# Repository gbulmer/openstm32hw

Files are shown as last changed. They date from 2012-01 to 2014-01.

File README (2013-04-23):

openstm32hw README

The aim is to provide Open Source hardware designs for STM32.

This repository grew from a discussion thread on LeafLabs Maple forum:
http://forums.leaflabs.com/topic.php?id=1303

It was initially triggered by ala42 who had released a first cut at libmaple for STM32F4:
http://forums.leaflabs.com/topic.php?id=1268&page=2#post-7828

and siy's hardware design:
http://forums.leaflabs.com/topic.php?id=1303&page=2&replies=46#post-7882

Subdirs:

	MM4 - Leaf Labs Maple Mini clone for 64 pin F1/L1/F4 processors
		in 0.8" width and 2 layers.

	Mini64 - STM32 development board for OpenSTM32
		 Features:
		 - Small (52x38.4mm) breadboard compatible design.
		 - Support for STM32F103/F2xx/F4xx in 64-pin packages.
		 - Uses Eagle 5.1

	Mini48 - Reworked version of Maple Mini suitable for DIY PCB production
		and on-board RTC crystal. Uses Eagle 5.1

	Mini48U - Ultimate version of Mini48. Still suitable for DIY PCB production
		but smaller parts (0402) and optimized layout allowed make it in the
		format of original Maple Mini with 0.6" pin header rows pitch.
		Uses Eagle 5.1

	Mini48SE - This version is very similar to Maple Mini, but it does not 
		preserve its pinout. It also heavily utilizes second side to 
		achieve maximal possible density. As a consequence this version 
		is probably smallest STM32F103Cxx board - it has 0.5" pitch 
		and size is only 50.5x15mm. At the same time board uses no 
		extremely small components - all resistors and capacitors 
		are 0603 (one even 0805), LED - 1206, LDO - 1117.
		Uses Eagle 6.3.0
		The design is tested.

	Mini64SE - Different approach to boards based on MCU in LQFP64 package. 
		It has DIP48 format with 0.8" pitch. The design follows same 
		approach as Mini48SE and utilizes both sides. Separate 
		versions of design for F1 and F2/F4 series are provided. 
		Version for F2/F4 uses different ESD protection and lacks 
		external disconnect cirquitry. These changes are necessary 
		to enable F2/F4 chips work properly in all supported USB modes
		(Device/OTG) and with different powering (self powering and 
		bus powering).
		Uses Eagle 6.3.0 
		Design for F1 is tested, design for F4 still is not yet tested.

	Orone-mini - series of boards intended to be more easily 'DIY-able'
		than LeafLabs Maple-mini, and incorporate several improvements.
		The first boards, Orone-mini-S8x have pins 0.2" wider 
		than Maple-mini. They are otherwise software and pin-compatible 
		with Maple-mini (exception is 'av+' which is intended to 
		improve the power supply capability). 
                Not yet tested.

	PiXe-2: 'Stamp' format, 64pin STM32F103 MCU. Eagle 5.1
                Features: 
		- Dual-in-line 0.1" grid
		- 0805 or larger parts -> easier assembly
		- Internal Maple pins available & re-configurable
		- modest 10mil track/space rules DIY-able

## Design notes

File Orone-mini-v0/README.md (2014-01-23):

Orone-mini designs
==================

Orone-mini's are designed to be software and mostly hardware compatible with LeafLabs Maple-mini. Some improvements have been inspired by Siy's mini48. These boards were also inspired  by the availability of STM32F303 in 48pin LQFP packages. Please note, boards will be tested first using STM32F103 before STM32F303 testing.

Maple-mini improvements
-----------------------
LeafLabs Maple-mini is a very impressive and useful Open Source Hardware development board. It offers approximately 4x more memory and CPU performance than an Arduino UNO, much improved peripherals, and about 50% more I/O pins in a tiny package that fits into a 48pin DIL IC socket. It is supported by an Open Source IDE and library similar to the Arduino UNO. 

However there are areas that are improved by Orone-mini designs:  
1.	Two-layer PCB, and so can be modified using 'free' Eagle CAD (unlike 4-layer which requires a commercial license)  
2.	DIY-assemblable; this is outlined below  
3.	More robust main power supply for operation above 6V; better current supply to e.g. LEDs and external digital electronics  
4.	USB Electro-Static Discharge (ESD) protection for Host PC and Orone-mini  
5.	USB overvoltage protection, protecting Orone-mini's USB power connection  
6.	Extra 2-pin molex socket for easier-to-connect external power  
7.	Power-on indicator  
8.	More robust through-hole mini-USB socket  
9.	Larger silk screen for easier readability  
10.	Silk screen warns of dedicated USB pins, and shows JTAG-SWD pins for extrnal debugger  
11.	Reduced-cost of capacitor C1 by using larger size (2917/7343)  
12.	Access to all STM32F signals; two are not connected to header pins  
13.	Access to the USB input voltage (after polyfuse protection) for 5V power for external electronics  
14.	Access to diode-protected but unregulated input voltage, for external electronics     
15.	Manual control of the USB enumeration mechanism to simplify using STM32F303 manufactured-in USB bootloader. The USB 'DISC' signal, along with ground, can be accessed using a 2 x 0.1" header.  
16.	All parts are straightforward to source, and available from a variety of sources. The Bill of Materials identifies several suppliers
17    Connected USB shield to USB Ground to reduce EM emission, using RC filter to avoid ground loops  

These boards are designed to be DIY-assemblable, but otherwise software and signal compatible with Maple-mini. 

All designs are breadboard-friendly form-factors; all pins are on breadboard 0.1" grid. However, initial designs have header pins spaced 0.8" apart, wider than Maple-mini's 0.6" header pins.

*	**Orone-mini-S8A** - Maple-mini compatible STM32F development board.  
	*Format*: two 20pin headers 0.8" apart. 1206 Components, SOT-223 voltage regulator uses LM2937-style, 'tab-is-ground', footprint  
	Improves on first 5 areas  
	Successfully tested by LeafLabs forum member 'ventosus'.

*	**Orone-mini-S8C** - Superseded by Orone-mini-S8D.    

*	**Orone-mini-S8D** - Superseded by Orone-mini-S8E.    

*	**Orone-mini-S8E** - Maple-mini compatible STM32F development board.    
	*Format*: two 20pin headers 0.8" apart.  
	*Electronics*:1206 Components except NUF2042XV6, C1 is larger 2917/7343, SOT-223 voltage regulator uses LM2937-style, 'tab-is-ground', footprint.  
	PCB requires 6mil track and 6mil space manufacturing capability  
	Similar to Orone-mini-S8A, S8C and S8D, however is physically different from Orone-mini-S8D, and so it's a new part number.  
	Incorporates ten improvements.  
	Not yet tested.

*	**Orone-mini-S8H** - Maple-mini compatible STM32F development board.    
	*Format*: two 20pin headers 0.8" apart.   
	*Electronics*:1206 Components except NUF2042XV6, C1 is larger 2917/7343, SOT-223 voltage regulator uses LM2937-style, 'tab-is-ground', footprint.  
	PCB requires *8mil track and 8mil space* manufacturing capability    
	Similar to Orone-mini-S8A, S8C and S8D, however uses coarser, lower-cost PCB manufacturing rules.  
	Incorporates ten improvements.  
	Successfuly tested by Forum members Crenn and Adam

*	**Orone-mini-S8J** - Maple-mini compatible STM32F development board.    
	*Format*: two 20pin headers 0.8" apart.   
	*Electronics*:1206 Components or larger, except C1 (2917/7343), SOT-223 voltage regulator uses LM2937-style, 'tab-is-ground', footprint.  
	PCB requires *8mil track and 8mil space*, 0.4mm via manufacturing capability    
	Similar to Orone-mini-S8A, S8C and S8D, however uses coarser, lower-cost PCB manufacturing rules.  
	Incorporates sixteen improvements.  
	Not yet tested.

*	**Orone-mini-S8K** - Maple-mini compatible STM32F development board.    
	*Format*: two 20pin headers 0.8" apart.   
	*Electronics*:1206 Components or larger, except C1 (2917/7343), SOT-223 voltage regulator uses LM2937-style, 'tab-is-ground', footprint.  
	PCB requires *8mil track and 8mil space*, 0.4mm via manufacturing capability    
	Similar to Orone-mini-S8A, S8C and S8D, however uses coarser, lower-cost PCB manufacturing rules.  
	Incorporates all improvements.  
	Not yet tested.

*	**CAM/OSHPark-Orone-mini-S8E-v0.cam** - OSHpark.com Eagle CAM file  
	Not yet tested.

Maple-mini Software compatibility
---------------------------------
Orone-mini boards are designed to be completely software and bootloader compatible with Maple-mini. So all existing Maple-mini software should work.

Maple-mini Hardware compatibility
---------------------------------
Orone-mini-S8x boards are not physically compatible with Maple-mini because the pin headers have been moved from 0.6" spacing to 0.8" spacing. This was a result of the increased component size used on Orone-mini. The increased component size is driven by the aim to make Orone-mini DIY-assemblable. 

Orone-mini-S8J pins carry identical signals to Maple-mini. Unlike Orone-mini-S8A-S8H, Orone-mini-S8J 'av+' pin is also identical to Maple-mini. Orone-mini-S8J supplies the 'av+' voltage from the analogue power regulator. The assumption is this will be a lower noise power source than the digital power supply. However this is not yet tested.

Orone-mini version S8A-S8H have one change to the header pins. The Maple-mini's 'av+' power was supplied by a small voltage regulator which might close down, or be damaged when the Maple-mini was used with a power supply voltage much higher than USB's voltage. Orone-mini S8A-S8H supplies power to the 'av+' pin from a slightly larger capacity voltage regulator. The intent is to avoid damage to the small voltage regulator. 

The orone-mini silk screen is larger-size text, and hence contains less information, than Maple-mini. The increase in size is intended to be easier to read, and easier for PCB makers to produce.

DIY-assemblable
---------------
The Maple-mini uses a 4-layer Printed Circuit Board, which can not be modified with the 'free' version of Eagle ECAD. 4-layer boards are also relatively expensive. Hence, this board is a 2-layer board which can be modified using 'free' Eagle ECAD, and the PCB should be much lower cost to manufacture. The board is designed to comply with all Eagle Design Rules from OSHPark.com and Seeedstudio (see Design Rules below)

Many of the Maple-mini parts are very small '0402' size. These have been replaced by 1206 (nine times bigger). This necessitated the increase in board size, which caused the spacing between pin-headers to be increased from 0.6" to 0.8". However 1206 is a component size used in UK schools to introduce 13yo school children to assembling SMD boards. So I hope will be well within the ability of many people. 

Earlier designs used a very small part for Electro-Static Discharge (ESD) protection. This has been replaced by a combination of larger parts, which should be less challenging to assemble. Maple-mini has no ESD protection, so this is additional functionality to Maple-mini.

The Maple-mini has SMD parts on both sides of the board. This is relatively difficult to make using some DIY-friendly SMD techniques. Hence all 'top' SMD components have been changed to 'thru-hole' allowing for a wider range of DIY SMD assembly techniques. The specific components effected are the USB socket, buttons and LEDs. The thru-hole components should also be more robust than the original SMD components.

PCB Design Rules
----------------------
The Printed Circuit Board (PCBs) has been designed using widely available PCB manufacturing tolerances, specifically 8mil track, 8mil space. The smallest drill is 0.5mm (with one 0.4mm exception on S8J/S8K). These manufacturing tolerances are supported by OSHPark.com and Seeedstudio 'Fusion PCB service'. (If you use other PCB manufacturers, would you please feedback your results?)

There are several sets of Design Rule check errors which are flagged by Eagle. None of these prevent the boards being made.

OSHPark Design Rules prevent via 'tenting'; Eagle generated solder mask will not cover *any* vias with solder mask. Hence any text for a silk screen (including tNames and bNames) which print across vias are flagged as "Stop Mask errors".  Small vias should be 'tented'. Set the DRC check->Masks->Limit to 20mil, which will cover vias with a 20mil or smaller (0.5mm) drill with solder mask (tented vias). The Design Rules embedded in this PCB CAD tents vias, so this is only an issue if you load OSHParks DRU file.   

Thanks to
---------
Mark Rafter and Jeff Smith; Tony Wilcox, Chris Evans and David Hannaford of Midlands Micromouse and Robotics Club for advice, encouragement and expertise; Keith, Pete and Bill of Techwizz for discussions and feedback; Siy, feurig, ventosus, ala42, crenn, soycamo and everyone who shared ideas, built boards and contributed at LeafLabs forum; Laen of OSHPark.com for PCB & CAM help and expertise. Special thanks to Pete Harrison for sharing his knowledge, experience and good humour, and to LeafLabs for developing the Maple-IDE and Maple-mini.

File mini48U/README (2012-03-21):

Mini48U is a STM32 development board for OpenSTM32 project (https://github.com/gbulmer/openstm32).
This design is significantly modified Maple Mini R2 and further development of Mini48 
with some changes in schematic (no separate analog ground, added RTC crystal comparing to Maple Mini
and differently connecter RESET pull up resistor) and reworked Mini48 PCB for 0.6" row header spacing.

Copyright (C) LeafLabs (sorry, don't know exact years) 
Changes Copyright (C) 2012 Sergiy Yevtushenko.

Just like original design, modified version is distributed under terms and conditions
of Creative Commons Attribution-ShareAlike license 
(see http://creativecommons.org/licenses/by-sa/3.0/legalcode for details).

Features:
- Small (51.2x18.6mm) breadboard compatible design.
- Compatible with Maple Mini, although ADC noise characteristics might be worse
- RTC crystal on board

Two versions of the board are present. The design of both is very similar, the differences lie in used 
components. Version 0.6.9 uses smaller parts for USB circuit and buttons. Also it attempts to solve 
main problem of original Maple Mini and uses LM1117 for main power LDO in SOT223 package.

The design files were created in Eagle 5.11 (version 6.1) and Eagle 6.1 (version 6.9).

Comments and suggestions are welcome.

Regards,
    Sergiy Yevtushenko <Sergiy.Yevtushenko@gmail.com>

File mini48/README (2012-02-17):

Mini48 is a STM32 development board for OpenSTM32 project (https://github.com/gbulmer/openstm32).
This design is significantly modified Maple Mini R2 with some changes in schematic (no separate
analog ground, added RTC crystal) and completely new PCB (single layer, 0.7" row header spacing).

Copyright (C) LeafLabs (sorry, don't know exact years) 
Changes Copyright (C) 2012 Sergiy Yevtushenko.

Just like original design, modified version is distributed under terms and conditions
of Creative Commons Attribution-ShareAlike license 
(see http://creativecommons.org/licenses/by-sa/3.0/legalcode for details).

Features:
- Small (51.4x21.2mm) breadboard compatible design.
- Compatible with Maple Mini, although ADC noise characteristics might be worse
- RTC crystal on board

The design files were created in Eagle 5.11. Pictures of board can be found at 
https://picasaweb.google.com/101499174242780444159/Mini48.

At present design is single sided and suitable for DIY PCB production, although the requirements
to the production process is quite high - board uses 0.15/0.15mm traces/spaces and designed with
presence of solder mask in mind. The design is optimized for dry film negative photoresist process. 
Design files as-is are ready to use for ordering boards at some PCB production service.
Although they can be used for DIY production too, it might be useful to do following changes 
in the design files before creating photomask:

- Increase width of the dimension rectangle to 0.2mm and include it into top layer and 
  solder mask photomasks.
- Change width of default net class tracks to 0.17mm.
- Change width of vcc net class tracks except GND polygon to 0.32mm. 
- Change width of GND polygon wire to 0.1mm

NOTE: After these changes board will not pass DRC! If you plan make further modifications in the 
PCB changed as described above, change DRC rules accordingly.

Comments and suggestions are welcome.

Regards,
    Sergiy Yevtushenko <Sergiy.Yevtushenko@gmail.com>

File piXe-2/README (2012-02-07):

piXe-2 README

PiXe-2 Is a 'Stamp' format, Microcontroller board using a 64pin (LQFP64) ST Micro STM32F Cortex-M3.

The aim is to develop a board suitable for relatively inexperienced microcontroller users who'd like to progress beyond Arduino ATmega boards.

This design is a 'place-holder' for a new design, see "Work-In-Progress".

Pins are aligned to 0.1" grid, so it can be inserted into breadboard or veroboard.
Pins are on 1.2" pitch, and the board dimensions are 2.9" x 1.4"
It is a double layer board, with all components on one side.

All STM32F pins are brought to header pins except:
- USB - these connect directly to the host PC, 
        so the pins are not available on an pin
- Main Crystal - these have an onboard crystal

The silk screen carries LeafLabs' Maple pin numbers, so existing Maple programs would work unmodified.

All internal connections are Maple compatible, so an unmodified Maple Bootloader would work. 

Internal connections between pins, required for Maple compatibility, use 'solder bridges', and so can be severed. This enables alternative pins to be used for internal connections, though the bootloader will likely need to be modified.

The external power source 'BAT' pin uses a 'solder bridge' to connect to board power, and so can be severed. This would enable the STM32FReal-Time-clock to be powered from an external power source, such as a hearing-aid battery.

The design uses 10mil track 10mil space except for connection to the 0.5mm pitch STM32F. Parts are relatively large 0805, or larger to faciltate hand assembly by less experienced builders. The board has been fabricated using using DIY techniques. 

The Board PDF has had copper pours 'ripped up' to make the tracks easier to see. It has quite intricate ground planes to reduce crosstalk between signals.

Work-In-Progress
----------------
This design is undergoing significant change to redue the board size, accommodate STM32F4, and improve the USB interface electronics. 

WARNING:
This design has not been debugged.

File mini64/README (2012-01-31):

Mini64 is a STM32 development board for OpenSTM32 project (https://github.com/gbulmer/openstm32).

Features:
- Small (52x38.4mm) breadboard compatible design.
- Support for STM32F103/F2xx/F4xx in 64-pin packages.
- 3 separate voltage regulators - two small current LDOs for MCU (separate for analog/digital parts) and one 
  800ma LDO for sourcing external load.
- LiPol battery charger
- RTC crystal on board
- CR2032 battery holder for RTC on board
- Automatic power source selection
- One user button connected as in Maple board
- Two user LEDs, one connected as in Maple board and one connected as in Maple Mini board

The design files were created in Eagle 5.11.

At present design is single sided and suitable for DIY PCB production, although the requirements
to the production process is quite high - board uses 0.15/0.15mm traces/spaces and designed with
presence of solder mask in mind. The design is optimized for dry film negative photoresist process. 
Design files as-is are ready to use for ordering boards at some PCB production service.
Although they can be used For DIY production too, it might be useful to do following changes 
in the design files before creating photomask:

- Increase width of the dimension rectangle to 0.2mm and include it into top layer and 
  solder mask photomasks.
- Change width of default net class tracks to 0.17mm.
- Change width of vcc net class tracks except GND polygon to 0.32mm. 
- Change width of GND polygon wire to 0.1mm

NOTE: After these changes board will not pass DRC! If you plan make further modifications in the 
PCB changed as described above, change DRC rules accordingly.

Comments and suggestions are welcome.

Regards,
    Sergiy Yevtushenko <Sergiy.Yevtushenko@gmail.com>

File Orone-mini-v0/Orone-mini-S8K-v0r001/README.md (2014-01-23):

Orone-mini-S8K-v0r001
=====================

Maple-mini compatible STM32F development board. 

This board is a significant evolution of Orone-mini-S8H. 
Specifically, the NUF2042XV6 USB EMI, termination and ESD device has been replaced. Several makers feedback that it was awkwardly small and fiddly to place.

The replacement part is an STF202-22, which is 4x bigger than the NUF2042XV6.   This STF202-22 is used in such a way that its Vusb ESD and overvoltage protection can't protect the Vusb line. So a separate TVS diode is used to protect the Vusb connection.

All earlier Orone-mini-S8x boards had the AV+ supply voltage header pin connected to the main digital power supply. This was done in order to reduce the problem which had effected Maple-mini boards of too much power being drawn from AV+, and damaging the voltage regulator. 

However, Ventosus made measurements of ADC noise, using circuits powered buy the on-board power supply. These ranked the ADC noise performance as Maple analogue supply best, then Orone-mini-S8H-v0r001's digital supply, then Maple's digital supply. 

Orone-mini-S8K-v0r001's analogue power supply has been connected to av+, to improve Orone-mini's ADC noise. 

PLEASE NOTE the av+ power supply should not be used above an input voltage of approximately 9V and 20mA, as the small voltage regulator may overheat, shutdown or be damaged.

Orone-mini-S8H's power routing and ground plane have been reworked to reduce electrical noise.

This board has not been made and tested yet. It is being released now to gather feedback, and hopefully encourage people to test it. The board has been designed for manufacture using two PCB makers. However, a goal is to ensure it is manufacturable by a wider range of PCB makers, so please feedback.

This is board designed to be DIY-assemblable, but otherwise software and signal compatible with Maple-mini. It has been inspired by some of Siy's mini48 innovations, and also the availability of STM32F303 in 48pin LQFP packages.

It is a breadboard-friendly form-factor; all pins are on breadboard 0.1" grid. Unlike Maple-mini, the two 20pin 0.1" headers are 0.8", and not 0.6" apart. However it is still narrow and short enough to fit into single breadboards.

Maple-mini C1 1206-case-size has been replaced by a 2917 (7343 Metric) case size. 
Orone-mini-S8K brings two extra signals, and two new voltages, to header pads compared to Maple-mini. These additions do not effect any Maple-mini pins. The pads are on the same 0.1" grid as the headers.

Orone-mini improvements over Maple-mini
-----------------------
LeafLabs Maple-mini is a very impressive and useful Open Source Hardware development board. It offers approximately 4x more memory and CPU performance than an Arduino UNO, much improved peripherals, and about 50% more I/O pins in a tiny package that fits into a 40pin DIL IC socket. It is supported by an Open Source IDE and library similar to the Arduino UNO. 

However there are areas that can be improved:  
1.	Two-layer PCB, and so can be modified using 'free' Eagle CAD (unlike 4-layer which requires a commercial license)  
2.	DIY-assemblable; this is outlined elswhere  
3.	More robust main power supply for operation above 6V; better current supply to e.g. LEDs and external digital electronics  
4.	USB Electro-Static Discharge (ESD) protection for Host PC and Orone-mini  
5.	USB overvoltage protection, protecting Orone-mini's USB power connection  
6.	Extra 2-pin molex socket for easier-to-connect external power  
7.	Power-on indicator  
8.	More robust through-hole mini-USB socket  
9.	Larger silk screen for easier readability  
10.	Silk screen warns of dedicated USB pins, and shows JTAG-SWD pins for extrnal debugger  
11.	Reduced-cost of capacitor C1 by using larger size (2917/7343)  
12.	Access to all STM32F signals; two are not connected to header pins  
13.	Access to the USB input voltage (after polyfuse protection) for 5V power for external electronics  
14.	Access to diode-protected but unregulated input voltage, for external electronics     
15.	Manual control of the USB enumeration mechanism to simplify using STM32F303 manufactured-in USB bootloader. The USB 'DISC' signal, along with ground, can be accessed using a 2 x 0.1" header.  
16.	All parts are straightforward to source, and available from a variety of sources. The Bill of Materials identifies several suppliers
17    Connected USB shield to USB Ground to reduce EM emission, using RC filter to avoid ground loops  

All of these improvements are incorporated in the Orone-mini-S8K. The signal driving the User LED is on pin 33, next to pin 31. The DISC signal pad is on the standard 0.1" grid, but is interior to the board. Access to DISC enables the user to easily upload programs into an unprogrammed STM32F303, removing the need for any programming device (e.g. ST-LINK, USB-to-UART, or JTAG).

Vusb and Vx are on the bottom header row, and are not part of the Maple-mini compatible pins. These new voltages should only be used if you understand what you are doing. Vusb in particular is not fully protected, and connects to the host PCs USB socket. The pads are not labelled on top partly due to lack of space, and partly to avoid giving the impression that these are 'easy-to-use' signals.
 
The idea goal is to enable anyone stacking a daughterboard, to use the extra signals and voltages. Putting the pads on a 0.1" grid supports the use of simple daughterboard technology like matrix board, or strip board (e.g. Veroboard).

Maple-mini uses very small components in order to achieve its 0.6" pin-header spacing. They are unsuitable for most makers, and part of the goal of Orone-mini is to be DIY friendly. Also one of those Maple-mini components is expensive and difficult to source, C1, the power supply smoothing capacitor, which is a 1206 case size. Orone-mini replaces C1 with a larger, lower cost, 2917 (7343 Metric) case size. 

PCB Design Rules
----------------------
The Printed Circuit Board (PCBs) has been designed using widely available PCB manufacturing tolerances, specifically 8mil track, 8mil space. The smallest drill is 0.5mm (with one 0.4mm exception).  These manufacturing tolerances are supported by OSHPark.com and Seeedstudio 'Fusion PCB service'. (If you use other PCB manufacturers, would you please feedback your results?)

There are several sets of Design Rule check errors which are flagged by Eagle. None of these prevent the board being made:  

1.	There is a 'bridge' which is flagged as an error, but is manufacturable. The bridge is two touching pieces of copper, and looks like a piece of copper track. It is used to create a separate ground track to the analogue power supply. Eagle treats the bridge as two overlapping tracks, and flags clearance and overlap errors. These is be safe to ignore.  

2.	Several vias are close to SMD component pads. They are the same signal as the pad, and so should not cause electrical issues. However, they do fail default DRC checks. They have no impact on manufacturing the PCB. The errors are 'approved' in the PCB .brd file. C5 has one Clearance DRC error with a ground via. FUSE1 has 1 Overlap DRC error with a power via. D1 has 1 Overlap DRC error with a via.

3.    Two vias are near the 'tab' pin of the REG1 regulator cause DRC errors. The vias should conduct heat through to the larger area of copper on the reverse side of the board. There are several other 'heat-path vias' in the component side copper pour, but vias in REG1 tab-pin should be more effective. Note the vias are placed just beyond the edge of the tab-pin silk screen to reduce the likelihood of solder 'voids' under the pin.  

4.	The crystal routing is quite intricate. It contains Clearance (1), Keepout (3), Restrict (6) DRC Errors.

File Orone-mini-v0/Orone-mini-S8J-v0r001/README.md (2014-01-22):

Orone-mini-S8J-v0r001
=====================

Maple-mini compatible STM32F development board. 

This board is a significant evolution of Orone-mini-S8H. 
Specifically, the NUF2042XV6 USB EMI, termination and ESD device has been replaced. Several makers feedback that it was awkwardly small and fiddly to place.

The replacement part is an STF202-22, which is 4x bigger than the NUF2042XV6.   This STF202-22 is used in such a way that its Vusb ESD and overvoltage protection can't protect the Vusb line. So a separate TVS diode is used to protect the Vusb connection.

All earlier Orone-mini-S8x boards had the AV+ supply voltage header pin connected to the main digital power supply. This was done in order to reduce the problem which had effected Maple-mini boards of too much power being drawn from AV+, and damaging the voltage regulator. 

However, Ventosus made measurements of ADC noise, using circuits powered buy the on-board power supply. These ranked the ADC noise performance as Maple analogie supply best, then Orone-mini-S8H-v0r001's digital supply, then Maple's digital supply. 

Orone-mini-S8J-v0r001's analogue power supply has been connected to av+, to improve Orone-mini's ADC noise. 

PLEASE NOTE the av+ power supply should not be used above an input voltage of approximately 9V and 20mA, as the small voltage regulator may overheat, shutdown or be damaged.

Orone-mini-S8H's power routing and ground plane have been reworked to reduce electrical noise.

This board has not been made and tested yet. It is being released now to gather feedback, and hopefully encourage people to test it. The board has been designed for manufacture using two PCB makers. However, a goal is to ensure it is manufacturable by a wider range of PCB makers, so please feedback.

This is board designed to be DIY-assemblable, but otherwise software and signal compatible with Maple-mini. It has been inspired by some of Siy's mini48 innovations, and also the availability of STM32F303 in 48pin LQFP packages.

It is a breadboard-friendly form-factor; all pins are on breadboard 0.1" grid. Unlike Maple-mini, the two 20pin 0.1" headers are 0.8", and not 0.6" apart. However it is still narrow and short enough to fit into single breadboards.

Maple-mini C1 1206-case-size has been replaced by a 2917 (7343 Metric) case size. 
Orone-mini-S8J brings tw extra signals, and two new voltages, to header pads compared to Maple-mini. These additions do not effect any Maple-mini pins. The pads are on the same 0.1" grid as the headers.

Orone-mini improvements over Maple-mini
-----------------------
LeafLabs Maple-mini is a very impressive and useful Open Source Hardware development board. It offers approximately 4x more memory and CPU performance than an Arduino UNO, much improved peripherals, and about 50% more I/O pins in a tiny package that fits into a 40pin DIL IC socket. It is supported by an Open Source IDE and library similar to the Arduino UNO. 

However there are areas that can be improved:  
1.	DIY-assemblable - all parts are approaximately 1206 size or larger 
2.	Robust operation above 6V while providing current to e.g. LEDs and electronics  
3.	USB Electrostatic Discharge (ESD) protecting the Host PC and Orone-mini  
4.	Two-pin Molex kk Socket for easier-to-connect external power source
5.	Power-on indicator  
6.	Access to all STM32F signals; two signals are not connected to Maple-mini header pins    
7.	Access to Vusb, the 'raw' USB voltage source, and the 'pre-regulator' voltage Vx

All of these improvements are incorporated in the Orone-mini-S8J. The signal driving the User LED is on pin 33, next to pin 31. The DISC signal pad is on the standard 0.1" grid, but is interior to the board. Access to DISC enables the user to easily upload programs into an unprogrammed STM32F303, removing the need for any programming device (e.g. ST-LINK, USB-to-UART, or JTAG).

Vusb and Vx are on the bottom header row, and are not part of the Maple-mini compatible pins. These new voltages should only be used if you understand what you are doing. Vusb in particular is not fully protected, and connects to the host PCs USB socket. The pads are not labelled on top partly due to lack of space, and partly to avoid giving the impression that these are 'easy-to-use' signals.
 
The idea goal is to enable anyone stacking a daughterboard, to use the extra signals and voltages. Putting the pads on a 0.1" grid supports the use of simple daughterboard technology like matrix board, or strip board (e.g. Veroboard).

Maple-mini uses very small components in order to achieve its 0.6" pin-header spacing. They are unsuitable for most makers, and part of the goal of Orone-mini is to be DIY freiendly. Also one of those Maple-mini components is expensive and difficult to source, C1, the power supply smoothing capacitor, which is a 1206 case size. Orone-mini replaces C1 with a larger, lower cost, 2917 (7343 Metric) case size.

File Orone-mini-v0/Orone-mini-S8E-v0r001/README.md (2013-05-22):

Orone-mini-S8E-v0r001
=====================

Maple-mini compatible STM32F development board. 

This board has not been made and tested yet. It is being released now to gather feedback, and hopefully encourage people to test it. The board has been designed for manufacture using two PCB makers. However, a goal is to ensure it is manufacturable by a wider range of PCB makers, so please feedback.

This is board designed to be DIY-assemblable, but otherwise software and signal compatible with Maple-mini. It has been inspired by some of Siy's mini48 innovations, and also the availability of STM32F303 in 48pin LQFP packages.

It is a breadboard-friendly form-factor; all pins are on breadboard 0.1" grid. Unlike Maple-mini, the two 20pin 0.1" headers are 0.8", and not 0.6" apart. However it is still narrow and short enough to fit into single breadboards.

Maple-mini C1 1206-case-size has been replaced by a 2917 (7343 Metric) case size. 
Orone-mini-S8E brings two extra signals, and two extra voltages to pads compared to Maple-mini. One signal (for the LED) and the two voltages are on the headers 0.1" grid. The USB 'DISC' signal is paired with a Ground pad, 0.1" away, enabling DISC to be shorted to ground with a jumper using a 2x0.1" header.

Maple-mini improvements
-----------------------
LeafLabs Maple-mini is a very impressive and useful Open Source Hardware development board. It offers approximately 4x more memory and CPU performance than an Arduino UNO, much improved peripherals, and about 50% more I/O pins in a tiny package that fits into a 40pin DIL IC socket. It is supported by an Open Source IDE and library similar to the Arduino UNO. 

However there are areas that can be improved:  
1.	DIY-assemblable; this is outlined below  
2.	Robust operation above 6V while providing current to e.g. LEDs and electronics  
3.	USB Electro-static Discharge (ESD) protecting the Host PC and Orone-mini  
4.	Socket for easier-to-connect external power  
5.	Power-on indicator  
6.	Reduced-cost of capacitor C1 by using larger size (2917/7343)  
7.	Access to all STM32F signals; two are not connected to header pins  
8.	Access to the USB input voltage (after polyfuse protection)  
9.	Access to diode-protected but unregulated input voltage  
10.	USB 'DISC' signal on 2 x 0.1" header to simplify STM32F303 USB boot

All of these improvements are incorporated in the Orone-mini-S8E. The signal driving the User LED (pin 33) is on a pad next to 31. The DISC signal pad is harder to access. It is not on the standard 0.1" grid, and is interior to the board. 

Vusb and Vx are in line with the bottom header row. These voltages should only be used if you understand what you are doing. Vusb is protected by the polyfuse (FUSE1), and is otherwise connected to the host PCs USB socket. The pads are not labelled on top partly due to lack of space, and partly to avoid giving the impression that these are 'safe' signals.

The aim of putting the extra signals on pads is to enable anyone making a daughterboard to easily access the extra signals and voltages. Putting signal the pads on a 0.1" grid supports the use of simple daughterboard technology like matrix board, or strip board (e.g. Veroboard).

Maple-mini uses very small components in order to achieve its 0.6" pin-header spacing. Maple-mini uses a 1206 case size for C1, the power supply smoothing capacitor. This size is expensive and difficult to source. On this Orone-mini, C1 has been replaced by a 2917 (7343 Metric) case size which is much lower cost.

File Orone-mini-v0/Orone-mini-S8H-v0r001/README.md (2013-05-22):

Orone-mini-S8H-v0r001
=====================

Maple-mini compatible STM32F development board. 

This board has not been made and tested yet. It is being released now to gather feedback, and hopefully encourage people to test it. The board has been designed for manufacture using two PCB makers. However, a goal is to ensure it is manufacturable by a wider range of PCB makers, so please feedback.

This is board designed to be DIY-assemblable, but otherwise software and signal compatible with Maple-mini. It has been inspired by some of Siy's mini48 innovations, and also the availability of STM32F303 in 48pin LQFP packages.

It is a breadboard-friendly form-factor; all pins are on breadboard 0.1" grid. Unlike Maple-mini, the two 20pin 0.1" headers are 0.8", and not 0.6" apart. However it is still narrow and short enough to fit into single breadboards.

Maple-mini C1 1206-case-size has been replaced by a 2917 (7343 Metric) case size. 
Orone-mini-S8H brings two extra signals, and two more voltages, to header pads compared to Maple-mini. The pads are on the same 0.1" grid as the headers.

Maple-mini improvements
-----------------------
LeafLabs Maple-mini is a very impressive and useful Open Source Hardware development board. It offers approximately 4x more memory and CPU performance than an Arduino UNO, much improved peripherals, and about 50% more I/O pins in a tiny package that fits into a 40pin DIL IC socket. It is supported by an Open Source IDE and library similar to the Arduino UNO. 

However there are areas that can be improved:  
1.	DIY-assemblable; this is outlined below  
2.	Robust operation above 6V while providing current to e.g. LEDs and electronics  
3.	USB Electro-static Discharge (ESD) protecting the Host PC and Orone-mini  
4.	Socket for easier-to-connect external power  
5.	Power-on indicator  
6.	Reduced-cost of capacitor C1 by using larger size (2917/7343)  
7.	Access to all STM32F signals; two are not connected to header pins  
8.	Access to the USB input voltage (after polyfuse protection)  
9.	Access to diode-protected but unregulated input voltage  
10.	USB 'DISC' signal on 2 x 0.1" header to simplify STM32F303 USB boot

All of these improvements are incorporated in the Orone-mini-S8H. The signal driving the User LED (pin 33) is on a pad aligned with the top header pins, next to 31. The DISC signal pad is harder to access. It is on the standard 0.1" grid, but is interior to the board.

Vusb and Vx are in line with the bottom header row. These voltages should only be used if you understand what you are doing. Vusb is protected by the polyfuse (FUSE1), and is otherwise connected to the host PCs USB socket. The pads are not labelled on top partly due to lack of space, and partly to avoid giving the impression that these are 'safe' signals.
 
The aim of putting the extra signals on pads is to enable anyone making a daughterboard to easily access the extra signals and voltages. Putting the pads on a 0.1" grid supports the use of simple daughterboard technology like matrix board, or strip board (e.g. Veroboard).

Maple-mini uses very small components in order to achieve its 0.6" pin-header spacing. Maple-mini uses a 1206 case size for C1, the power supply smoothing capacitor. This size is expensive and difficult to source. On this Orone-mini, C1 has been replaced by a 2917 (7343 Metric) case size which is much lower cost.

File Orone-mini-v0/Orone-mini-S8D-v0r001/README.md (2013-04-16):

Orone-mini-S8D-v0r001
=====================

Maple-mini compatible STM32F development board. 

This board has not been made and tested yet. It is being released now to gather feedback, and hopefully encourage people to test it. The board has been designed for manufacture using two PCB makers. However, a goal is to ensure it is manufacturable by a wider range of PCB makers, so please feedback.

This is board designed to be DIY-assemblable, but otherwise software and signal compatible with Maple-mini. It has been inspired by some of Siy's mini48 innovations, and also the availability of STM32F303 in 48pin LQFP packages.

It is a breadboard-friendly form-factor; all pins are on breadboard 0.1" grid. Unlike Maple-mini, the two 20pin 0.1" headers are 0.8", and not 0.6" apart. However it is still narrow and short enough to fit into single breadboards.

Maple-mini C1 1206-case-size has been replaced by a 2917 (7343 Metric) case size. 
Orone-mini-S8D brings two extra signals compared to Maple-mini to pads on the same 0.1" grid as the headers.

Maple-mini improvements
-----------------------
LeafLabs Maple-mini is a very impressive and useful Open Source Hardware development board. It offers approximately 4x more memory and CPU performance than an Arduino UNO, much improved peripherals, and about 50% more I/O pins in a tiny package that fits into a 40pin DIL IC socket. It is supported by an Open Source IDE and library similar to the Arduino UNO. 

However there are areas that can be improved:  
1.	DIY-assemblable  
2.	Robust operation above 6V while providing current to e.g. LEDs and electronics  
3.	USB Electro-static Discharge (ESD) protecting the Host PC and Orone-mini  
4.	Socket for easier-to-connect external power  
5.	Power-on indicator  
6.	Access to all STM32F signals; two signals are not connected to header pins    

All of these improvements are incorporated in the Orone-mini-S8D. The signal driving the User LED (pin 33) is on a pad next to 31. The DISC signal pad is harder to access. It is on the standard 0.1" grid, but is interior to the board. The idea is to enable anyone stacking a daughterboard, to use the extra two signals. Putting the signal pads on a 0.1" grid supports the use of simple daughterboard technology like matrix board, or strip board (e.g. Veroboard).

Maple-mini uses very small components in order to achieve its 0.6" pin-header spacing. One of those components is expensive and difficult to source, C1, the power supply smoothing capacitor. Maple-mini uses a 1206 case size for C1. This has been replaced by a 2917 (7343 Metric) case size.

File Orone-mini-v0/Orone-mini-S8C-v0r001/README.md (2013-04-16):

Orone-mini-S8C-v0r001
=====================

Maple-mini compatible STM32F development board. 

This board has not been made and tested yet. It is being released now to gather feedback, and hopefully encourage people to test it. The board has been designed for manufacture using two PCB makers. However, a goal is to ensure it is manufacturable by a wider range of PCB makers, so please feedback.

This is board designed to be DIY-assemblable, but otherwise software and signal compatible with Maple-mini. It has been inspired by some of Siy's mini48 innovations, and also the availability of STM32F303 in 48pin LQFP packages.

It is a breadboard-friendly form-factor; all pins are on breadboard 0.1" grid. Unlike Maple-mini, the two 20pin 0.1" headers are 0.8", and not 0.6" apart. However it is still narrow and short enough to fit into single breadboards.

Maple-mini C1 1206-case-size has been replaced by a 2917 (7343 Metric) case size. 

Maple-mini improvements
-----------------------
LeafLabs Maple-mini is a very impressive and useful Open Source Hardware development board. It offers approximately 4x more memory and CPU performance than an Arduino UNO, much improved peripherals, and about 50% more I/O pins in a tiny package that fits into a 40pin DIL IC socket. It is supported by an Open Source IDE and library similar to the Arduino UNO. 

However there are areas that can be improved:  
1.	DIY-assemblable  
2.	Robust operation above 6V while providing current to e.g. LEDs and electronics  
3.	USB Electro-static Discharge (ESD) protecting the Host PC and Orone-mini  
4.	Socket for easier-to-connect external power  
5.	Power-on indicator  
6.	Access to all STM32F signals; two are not connected to header pins  

All of these improvements are incorporated in the Orone-mini-S8C. The two signals of item 6, are not easy to access. Though both signals are on the standard 0.1" grid, they are on the interior of the board, and one signal is only available from the User LED pads. The idea is to enable anyone stacking a daughterboard, to use the extra two signals. Putting the signal pads on a 0.1" grid supports the use of simple daughterboard technology like matrix board, or strip board (e.g. Veroboard).

Maple-mini uses very small components in order to achieve its 0.6" pin-header spacing. One of those components is expensive and difficult to source, C1, the power supply smoothing capacitor. Maple-mini uses a 1206 case size for C1. This has been replaced by a 2917 (7343 Metric) case size.

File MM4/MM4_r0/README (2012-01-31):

This design is a clone of Leaf Labs Maple Mini board (called MM4) with the following variations
	from the original:

	- 0.8 inch pitch between connectors rather than 0.6". This means dual rows of 
		sip connectors are required rather than a 40 pin dip (a socket layout can 
		easily be defined for either LeafLabs or MM4 using 3 sip connectors.)

	- identical pin functions except for the above mentioned pitch change.

	- two layer layout in Eagle which can be modified with the free version of 
		Eagle (original was done with Eagle v6.1). Ground planes that are 
		as large as practical are used given the two layer constraint (modification 
		to internal power/ground planes is, of course, fairly straightforward, 
		but requires the much more expensive Eagle license).

	- 64 pin processor that can be STM32F10xC/D/E orSTM32F4 or STM32L1 series. This means 
		the F1 chip variants with larger memories can be used or the L1 low power series 
		(F1 and L1 require two solder bridge jumpers to be installed), or the faster Cortex-M4 F4 series.

	- considerably less detailed top silkscreen layer in this version of MM4.

	- The USB termination function has been re-implemented with a dedicated USB terminator
		chip that contains the termination resistors and the signalling resistor to
		describe the board to an up-stream host as a full speed USB peripheral.
		The disconnect function is then separately implemented with an open collector 
		inverter. The original implemented the signalling and disconnect via a 
		transistor/resistor network.

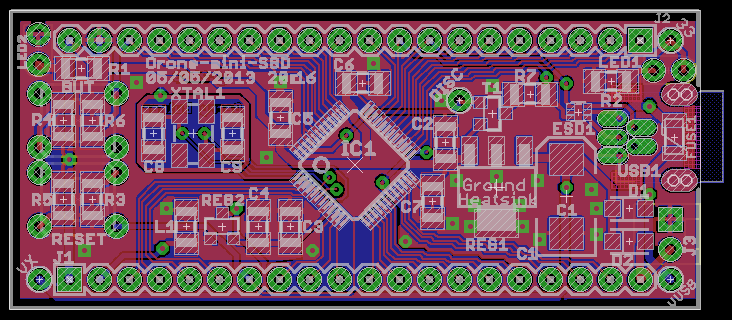
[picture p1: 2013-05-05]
Orone-mini-v0/Orone-mini-S8D-v0r001/Orone-mini-S8D-v0r001.png

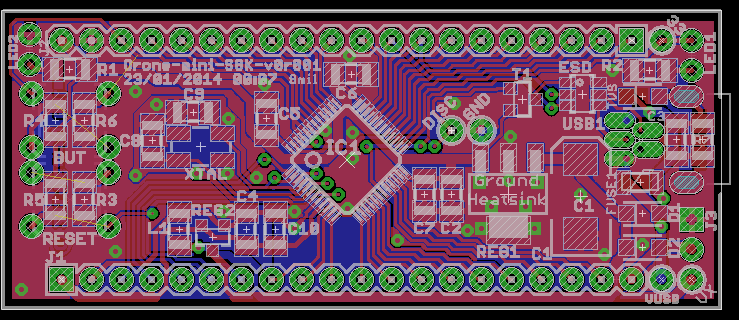
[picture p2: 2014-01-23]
Orone-mini-v0/Orone-mini-S8K-v0r001/Orone-mini-S8K-v0r001.brd.png

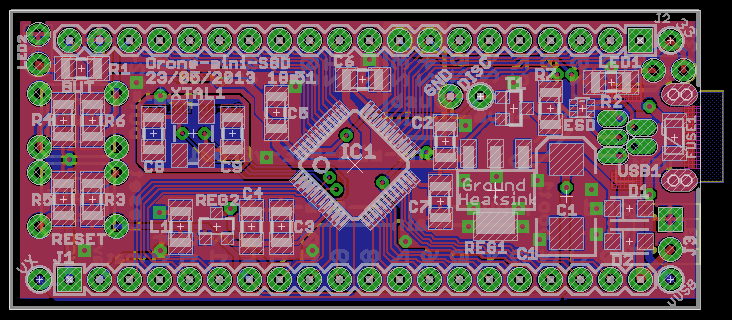
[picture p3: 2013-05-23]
Orone-mini-v0/Orone-mini-S8E-v0r001/Orone-mini-S8E-v0r001.png

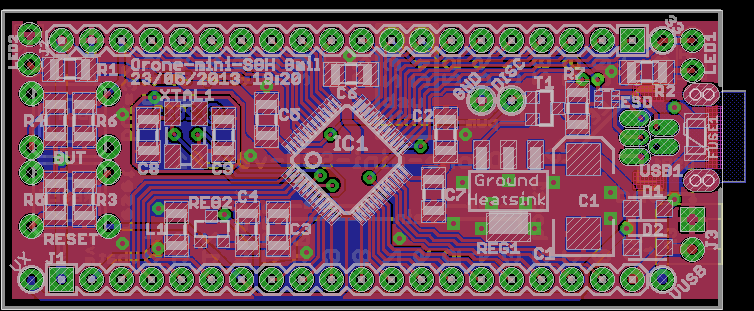
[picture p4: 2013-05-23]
Orone-mini-v0/Orone-mini-S8H-v0r001/Orone-mini-S8H-v0r001.png

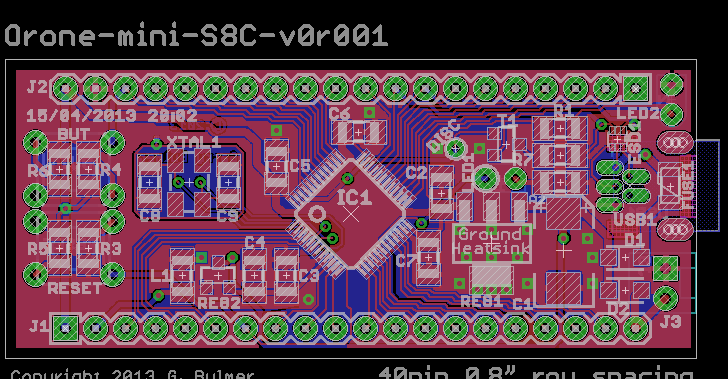
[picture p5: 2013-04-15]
Orone-mini-v0/Orone-mini-S8C-v0r001/Orone-mini-S8C-v0r001.png

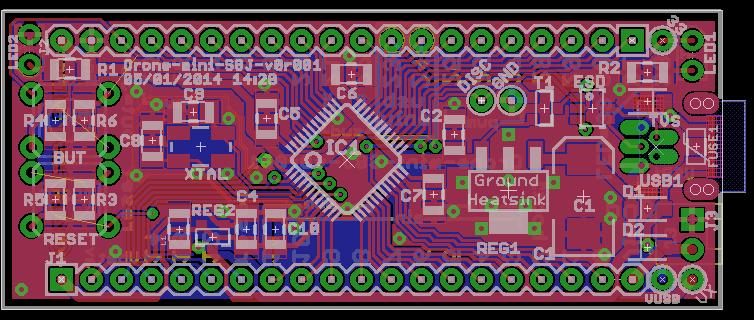
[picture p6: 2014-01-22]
Orone-mini-v0/Orone-mini-S8J-v0r001/Orone-mini-S8J-v0r001.png

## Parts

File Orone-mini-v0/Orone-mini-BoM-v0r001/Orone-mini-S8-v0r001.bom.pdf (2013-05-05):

Orone-mini-S8 Parts | Partlist exported at 14/04/2013 09:03
Qty | Parts | Value/Part # | Device | RS | Farnell | Future | Comment
0 | IC1 | STM32F103CB | STM32F103CB | 402-273 | 2215215 | STM32F103 CB | LQFP48 STM32F103
1 | | STM32F303CC | | 772-4857 | | | LQFP48 STM32F303
1 | L1 | 2512066017Y1 FAIR-RITE | INDUCTOR 1206 | 466-9603 | 1612060 | | Reduce electrical noise into analogue ground, av-0.08R 1A, 600R@100MHz
4 | R1, R2, R3, R4 | 1k | RESISTOR 1206 | 740-9117 (5%) | 2073877 | | LED current limit & switch pull-up/down, 10% okay
2 | R5, R6 | 10k | RESISTOR 1206 | 740-9081 (1%) | 2073878 | | switch pull-up/down, 10% tolerance is okay
1 | R7 | 1.5k | RESISTOR 1206 | 223-2287 (1%) or 740-9123 (5%) | 2073891 | | USB pull-up resistor
1 | C1 | 100uF/16V | CAP_POL7343 | 496-3646 or 684-3926 | 1754094 or 1658709 | | Main power smoothing capacitor must be able to withstand the external power Vin voltage
1 | C2 | 10uF | CAP 1206 | 723-6565 or 758-8093 etc. | 2113071 or 1828831 | | Multi-layer Ceramic X7R, 6.3V or higher
1 | C3 | 10nF | CAP 1206 | 669-8410 or 264-4141 etc | 1759350 or 1414713 | | Multi-layer Ceramic X7R, 6.3V or higher
4 | C4, C5, C6, C7 | 1uF | CAP 1206 | 648-0733 or 669-8448 etc. | 1759436 or 9227865 | | Multi-layer Ceramic X7R, 6.3V or higher
2 | C8, C9 | 18pF | CAP 1206 | 698-2841 or 648-0935 (0805) | 1650895 or 2218878 | | Hard to get in 1206, RS 698-2841 is 15pF, or RS 648-0935 (0805 case)
1 | XTAL1 | 5RCA08000123TF80Q3 | CRYSTAL 5X3.2 | 728-8272 | | | 8MHz 5x3.2mm 4-pad SMD Crystal
2 | BUT, RESET | FSM6JH | TAC_SWITCH PTH 6mm | 758-1953 or 758-1957 or 756-1543
1 | LED1 | L-2060GD | LED1.8MM-W | 228-5427 | 1142454 or 1045497 | | 1.8MM (T-3/4) Green User LED - e.g. Kingbright, Vishay or generic
1 | LED2 | L-2060ID or MCL914SRD | LED1.8MM-W | 228-5411 | 1142456 or 1045495 | | LED 1.8MM (T-3/4) Red Power-On LED - e.g. Kingbright, Vishay or generic
2 | D1, D2 | PMEG3010ER or PMEG3010EH | DIODE-SCHOTTKY SOD-123W | 485-606 | 1907686 | | 1A 30V or higher Schottky Diode
1 | T1 | PDTA114ET or MMUN2111LT1G | ES_PNP-DRIVER SOT23-3 | 484-3441 | 1907673 or 9556702 | | PNP ‘Digital Transistor’ includes
1 | REG1 | MIC5209-3.3YS | V_REG_LM293 7 SOT223 | 727-2586 | 2100322 or 1556725
1 | REG2 | MCP1703T-3302E/CB | MCP170X SOT23 | 669-4907 | 1439518
1 | ESD1 | NUF2042XV6 | NUF2042XV6 SOT563 | | | NUF2042XV 6T1G | NUF2042XV6T ESD protection and USB filter
1 | FUSE1 | 1206L050 (Littelfuse) or nanoSMDC050F/13.2 (TE) | PTCSMD | 138-679 | 1596993 or 1345942 | | 6V, 500mA Polyfuse 0.7R Max, 0.4R Typical. Littelfuse part numbers may be 1206L050YR or 1206L050-C
2 | J1, J2 | e.g. AW 110/20-T (Assman) | M20 | 674-2343 | | | 2 x 20pin 0.1” Headers. Almost any 0.1" pitch header pins could be used, could also use 0.1" pitch sockets.
1 | USB1 | USB-Mini-B/AB thru-hole. 56579-0519 or 54819-0519 Molex | USB-MINIB TH-ODRILL | 515-2011 or 515-2005 | 1125347 or 2133828 or 9786465 | | Thru-hole USB Mini B & AB same footprint
1 | J3 | Molex KK 22-23-2021 or 22-11-2022 or 22-27-2021 | M02POLAR | 679-5583 or 679-5515 or 483-8461 | 1462926 or 1865212 or 9731148 | | 2-pin, polarised, "External power" socket

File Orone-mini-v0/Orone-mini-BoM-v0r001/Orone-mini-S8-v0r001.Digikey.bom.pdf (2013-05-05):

Digi-Key Part # | Manufacturer | Manufacturers Part # Reference | Quantity 1 | Quantity 2 | Quantity 3 | Description | Comments | RoHS | Lead Free | REACH status
Digi-Key Teilenummer Hersteller | | Hersteller-Teilenummer KundenreferenzAnzahl 1 | | Anzahl 2 | Anzahl 3 | Beschreibung | Anmerkungen | RoHS Status | Bleifreier StatusREACH Status
497-13318-ND | STMICROELECTRONICS STM32F303CCT6 | 1 | 0 | 0 | IC MCU 32BIT 256KB FLASH 48LQFP RoHS-konform | Bleifrei | Nicht verfügbar
497-6288-ND | STMICROELECTRONICS STM32F103CBT6 | 1 | 0 | 0 | MCU ARM 128K FLASH/TIMER Andere Verpackung vorhanden RoHS-konform | | Bleifrei | Nicht betroffen
450-1652-ND | TE CONNECTIVITY ALCOSWITCH FSM6JH | 2 | 0 | 0 | SWITCH TACTILE SPST-NO 0.05A 12V RoHS-konform | Bleifrei | Nicht betroffen
718-1921-1-ND VISHAY SPRAGUE (VA) TL8A0107M010C | | 1 | 0 | 0 | CAP TANT 100UF 10V 20% 1206 Andere Verpackung vorhanden RoHS-konform | Bleifrei | Nicht verfügbar
311-1152-1-ND YAGEO (VA) | CC1206JRNPO9BN180 | 2 | 0 | 0 | CAP CER 18PF 50V 5% NPO 1206 Andere Verpackung vorhanden RoHS-konform | Bleifrei | Nicht betroffen
490-1755-1-ND MURATA ELECTRONICS (VA) GRM3195C1H113JA01D | 1 | 0 | 0 | CAP CER 0.011UF 50V 5% NP0 1206 Andere Verpackung vorhanden RoHS-konform | Bleifrei | Nicht betroffen
568-6512-1-ND NXP SEMICONDUCTORS (VA) PMEG3010BER,115 | 2 | 0 | 0 | DIODE SCHOTTKY 30V 1A SOD123W Andere Verpackung vorhanden RoHS-konform | Bleifrei | Nicht betroffen
NUF2042XV6T1GOSCT-ND ON SEMICONDUCTOR (VA) NUF2042XV6T1G | 1 | 0 | 0 | IC FILTER USB ESD PROTECT SOT363 Andere Verpackung vorhanden RoHS-konform | Bleifrei | Nicht betroffen
F2112CT-ND | LITTELFUSE INC (VA) 1206L050YR | 1 | 0 | 0 | FUSE PTC RESET 6V .50A 1206 Andere Verpackung vorhanden RoHS-konform | Bleifrei | Nicht verfügbar
P1.50KFCT-ND PANASONIC ELECTRONIC COMPONENTS (VA) ERJ-8ENF1501V | | 1 | 0 | 0 | RES 1.5K OHM 1/4W 1% 1206 SMD Andere Verpackung vorhanden RoHS-konform | Bleifrei | Nicht verfügbar
P10.5KFCT-ND PANASONIC ELECTRONIC COMPONENTS (VA) ERJ-8ENF1052V | | 2 | 0 | 0 | RES 10.5K OHM 1/4W 1% 1206 SMD Andere Verpackung vorhanden RoHS-konform | Bleifrei | Nicht verfügbar
541-1.05KFCT-NDVISHAY DALE (VA) CRCW12061K05FKEA | | 10 | 0 | 0 | RES 1.05K OHM 1/4W 1% 1206 SMD Andere Verpackung vorhanden RoHS-konform | Bleifrei | Nicht betroffen
576-1274-1-ND MICREL INC (VA)MIC5209-3.3YS TR | 1 | 0 | 0 | IC REG LDO 3.3V 0.5A SOT223 Andere Verpackung vorhanden RoHS-konform | Bleifrei | Nicht betroffen
MCP1703T-3302E/CBCT-ND MICROCHIP TECHNOLOGY (VA) MCP1703T-3302E/CB | 1 | 0 | 0 | IC REG LDO 3.3V 0.25A SOT23A-3 Andere Verpackung vorhanden RoHS-konform | Bleifrei | Nicht betroffen
568-6425-1-ND NXP SEMICONDUCTORS (VA) PDTA114ET,215 | 1 | 0 | 0 | TRANS PNP W/RES 50V SOT-23 Andere Verpackung vorhanden RoHS-konform | Bleifrei | Nicht betroffen
WM17121-ND | MOLEX INC | 565790519 | 1 | 0 | 0 | CONN RECEPT USB 5POS RT ANG PCB RoHS-konform | Bleifrei | Nicht betroffen
887-1452-1-ND TXC CORPORATION (VA) 7B-8.000MAAJ-T | 1 | 0 | 0 | CRYSTAL 8.000MHZ 18PF SMD Andere Verpackung vorhanden RoHS-konform | Bleifrei | Nicht betroffen
MU3261-601YCT-ND BOURNS INC (VA) MU3261-601Y | 1 | 0 | 0 | BEAD FERRITE 600 OHM 200MA 3216 Andere Verpackung vorhanden RoHS-konform | Bleifrei | Nicht verfügbar
445-4043-1-ND TDK CORPORATION (VA) C3216X7R1A106K160AC | 1 | 0 | 0 | CAP CER 10UF 10V 10% X7R 1206 Andere Verpackung vorhanden RoHS-konform | Bleifrei | Nicht betroffen
445-1592-1-ND TDK CORPORATION (VA) C3216X7R1E105K085AA | 4 | 0 | 0 | CAP CER 1UF 25V 10% X7R 1206 Andere Verpackung vorhanden RoHS-konform | Bleifrei | Nicht betroffen

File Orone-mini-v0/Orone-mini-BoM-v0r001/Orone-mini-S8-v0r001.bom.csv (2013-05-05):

 |  | Orone-mini-S8 Parts |  |  |  |  |  |  |  | Partlist exported at 14/04/2013 09:03
Qty | Parts | Value/Part # | Device | RS | RS £ | RS qty*£ | Farnell | Future | Future £ | Comment
0 | IC1 | STM32F103CB | STM32F103CB | 402-273 | £5.450 | £0.000 | 2215215 | STM32F103CB | £2.79 | LQFP48 STM32F103
1 |  | STM32F303CC |  | 772-4857 | £4.530 | £4.530 |  |  |  | LQFP48 STM32F303
1 | L1 | 2512066017Y1 FAIR-RITE | INDUCTOR 1206 | 466-9603 | £0.031 | £0.031 | 1612060 |  |  | Reduce electrical noise into analogue ground, av- 0.08R 1A, 600R@100MHz
4 | R1, R2, R3, R4 | 1k | RESISTOR 1206 | 740-9117 (5%) | £0.021 | £0.084 | 2073877 |  |  | LED current limit & switch pull-up/down, 10% okay
2 | R5, R6 | 10k | RESISTOR 1206 | 740-9081 (1%) | £0.020 | £0.040 | 2073878 |  |  | switch pull-up/down, 10% tolerance is okay
1 | R7 | 1.5k | RESISTOR 1206 | 223-2287 (1%) or 740-9123 (5%) | £0.020 | £0.020 | 2073891 |  |  | USB pull-up resistor
1 | C1 | 100uF/16V | CAP_POL7343 | 496-3646 or 684-3926 | £0.300 | £0.300 | 1754094 or 1658709 |  |  | Main power smoothing capacitor must be able to withstand the external power Vin voltage
1 | C2 | 10uF | CAP 1206 | 723-6565 or 758-8093 etc. | £0.110 | £0.110 | 2113071 or 1828831 |  |  | Multi-layer Ceramic X7R, 6.3V or higher
1 | C3 | 10nF | CAP 1206 | 669-8410 or 264-4141 etc | £0.044 | £0.044 | 1759350 or 1414713 |  |  | Multi-layer Ceramic X7R, 6.3V or higher
4 | C4, C5, C6, C7 | 1uF | CAP 1206 | 648-0733 or 669-8448 etc. | £0.070 | £0.280 | 1759436 or 9227865 |  |  | Multi-layer Ceramic X7R, 6.3V or higher
2 | C8, C9 | 18pF | CAP 1206 | 698-2841 or 648-0935 (0805) | £0.010 | £0.020 | 1650895 or 2218878 |  |  | Hard to get in 1206, RS 698-2841 is 15pF, or RS 648-0935 (0805 case)
1 | XTAL1 | 5RCA08000123TF80Q3 | CRYSTAL 5X3.2 | 728-8272 | £0.768 | £0.768 |  |  |  | 8MHz 5x3.2mm 4-pad SMD Crystal
2 | BUT, RESET | FSM6JH | TAC_SWITCH PTH 6mm | 758-1953 or 758-1957 or 756-1543 | £0.100 | £0.200
1 | LED1 | L-2060GD | LED1.8MM-W | 228-5427 | £0.130 | £0.130 | 1142454 or 1045497 |  |  | 1.8MM (T-3/4) Green User LED - e.g. Kingbright, Vishay or generic
1 | LED2 | L-2060ID or MCL914SRD | LED1.8MM-W | 228-5411 | £0.130 | £0.130 | 1142456 or 1045495 |  |  | LED 1.8MM (T-3/4) Red Power-On LED - e.g. Kingbright, Vishay or generic
2 | D1, D2 | PMEG3010ER or PMEG3010EH | DIODE-SCHOTTKY SOD-123W | 485-606 | £0.075 | £0.150 | 1907686 |  |  | 1A 30V or higher Schottky Diode
1 | T1 | PDTA114ET or MMUN2111LT1G | ES_PNP-DRIVER SOT23-3 | 484-3441 | £0.023 | £0.023 | 1907673 or 9556702 |  |  | PNP ‘Digital Transistor’ includes
1 | REG1 | MIC5209-3.3YS | V_REG_LM2937 SOT223 | 727-2586 | £1.078 | £1.078 | 2100322 or 1556725
1 | REG2 | MCP1703T-3302E/CB | MCP170X SOT23 | 669-4907 | £0.337 | £0.337 | 1439518
1 | ESD1 | NUF2042XV6 | NUF2042XV6 SOT563 |  |  | £0.000 |  | NUF2042XV6T1G | £0.113 | NUF2042XV6T ESD protection and USB filter
1 | FUSE1 | 1206L050 (Littelfuse) or nanoSMDC050F/13.2 (TE) | PTCSMD | 138-679 | £0.369 | £0.369 | 1596993 or 1345942 |  |  | 6V, 500mA Polyfuse 0.7R Max, 0.4R Typical. Littelfuse part numbers may be 1206L050YR or 1206L050-C
2 | J1, J2 | e.g. AW 110/20-T (Assman) | M20 | 674-2343 | £0.490 | £0.980 |  |  |  | 2 x 20pin 0.1” Headers. Almost any 0.1" pitch header pins could be used, could also use 0.1" pitch sockets.
1 | USB1 | USB-Mini-B/AB thru-hole. 56579-0519 or 54819-0519 Molex | USB-MINIB TH-ODRILL | 515-2011 or 515-2005 | £0.093 | £0.093 | 1125347 or 2133828 or 9786465 |  |  | Thru-hole USB Mini B & AB same footprint
1 | J3 | Molex KK 22-23-2021 or 22-11-2022 or 22-27-2021 | M02POLAR | 679-5583 or 679-5515 or 483-8461 | £0.066 | £0.066 | 1462926 or 1865212 or 9731148 |  |  | 2-pin, polarised, "External power" socket

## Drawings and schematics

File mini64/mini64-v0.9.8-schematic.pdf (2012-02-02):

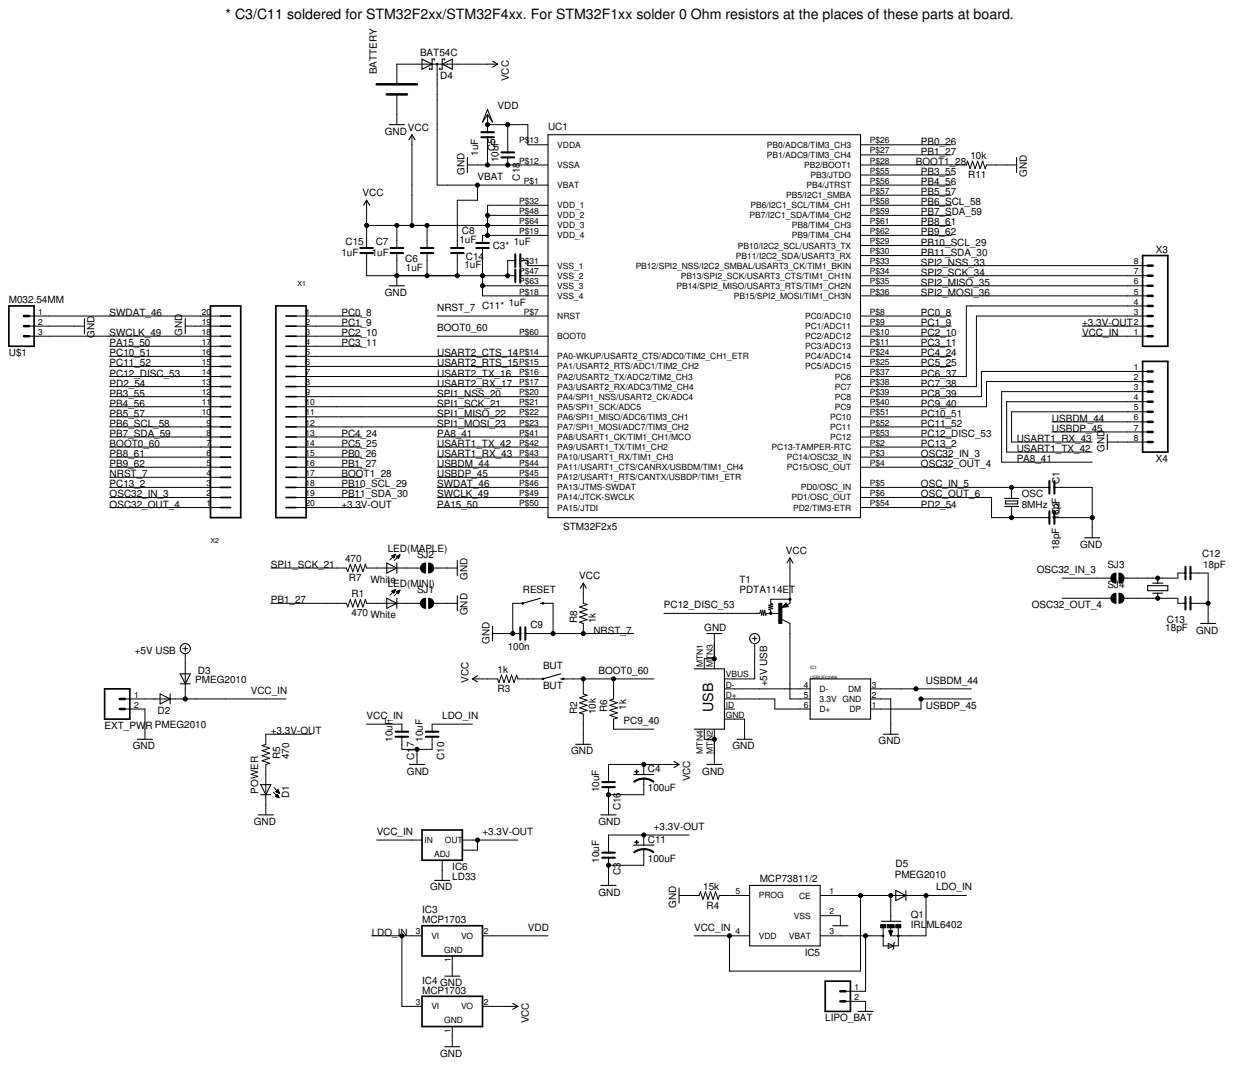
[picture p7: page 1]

* C3/C11 soldered for STM32F2xx/STM32F4xx. For STM32F1xx solder 0 Ohm resistors at the places of these parts at board.

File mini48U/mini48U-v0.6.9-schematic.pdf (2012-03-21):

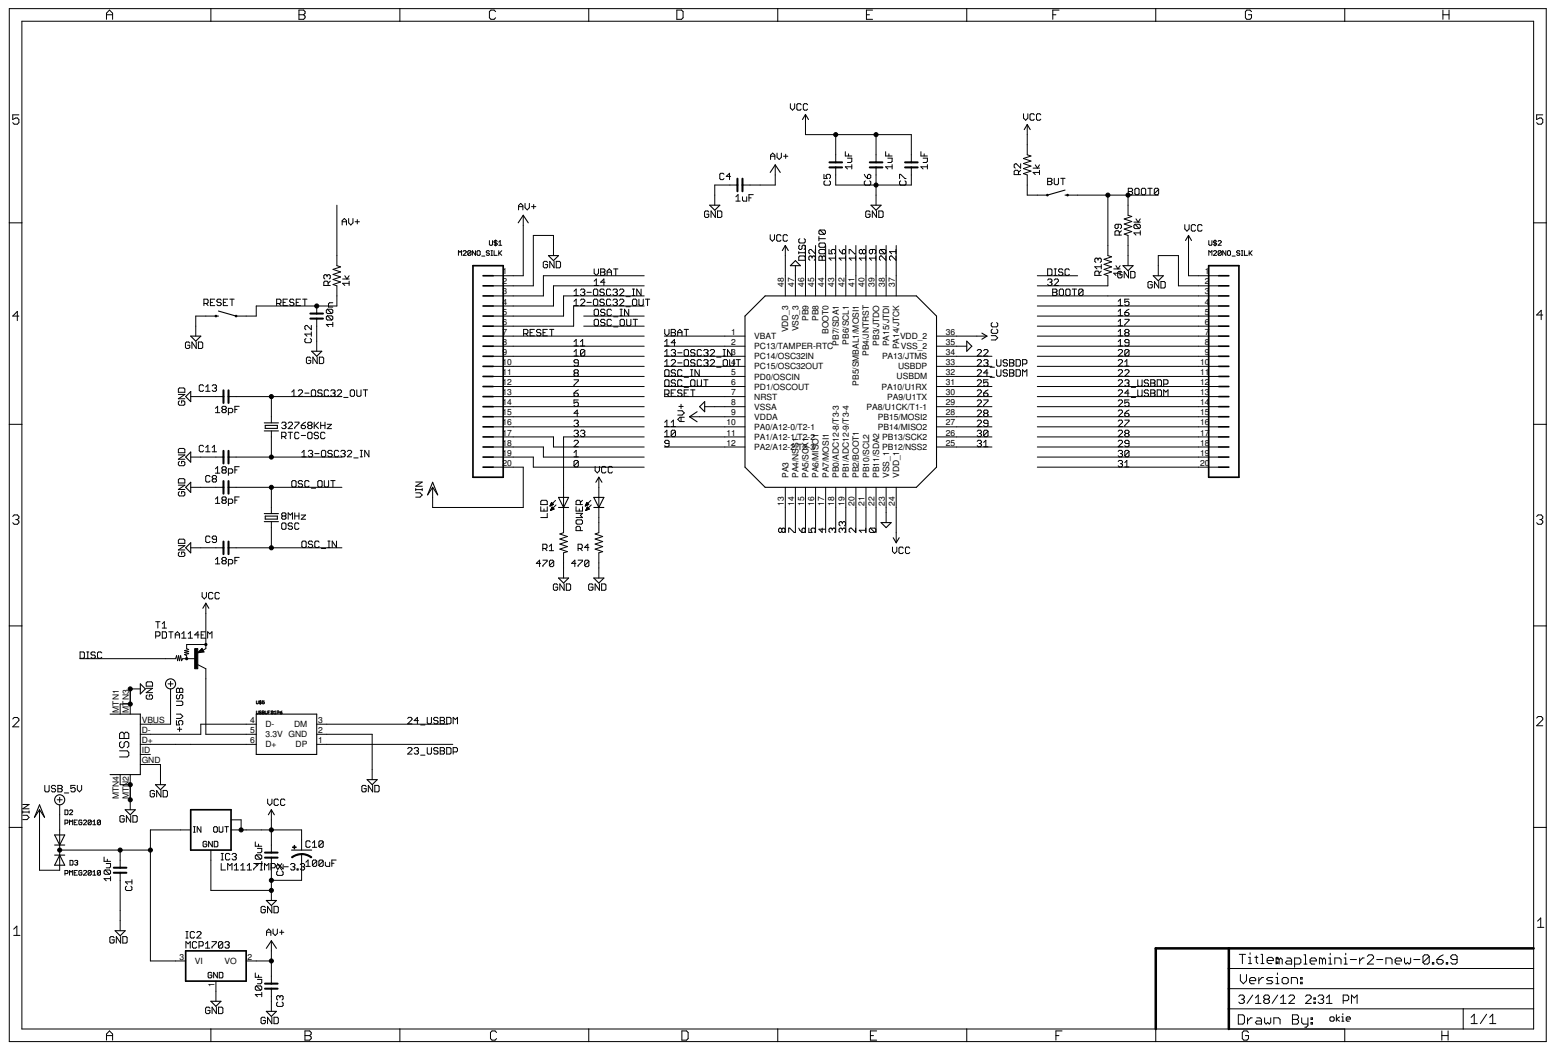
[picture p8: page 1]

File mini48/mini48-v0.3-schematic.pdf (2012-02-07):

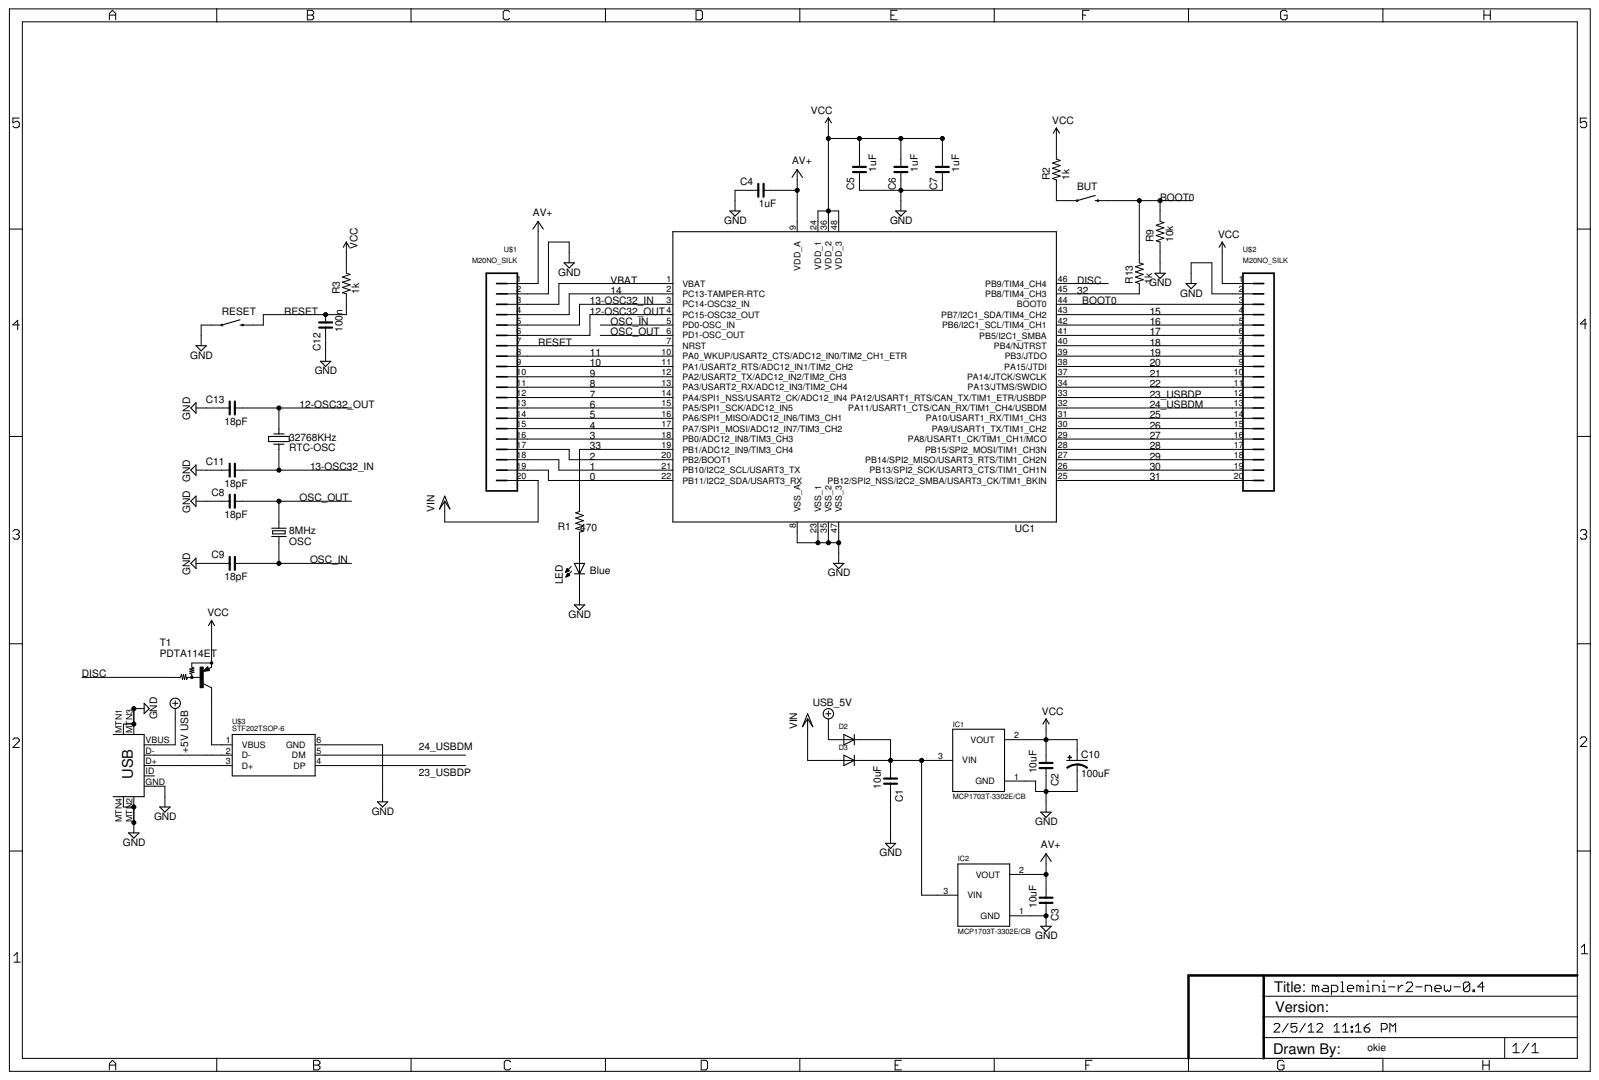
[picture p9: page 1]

2 20 | 29 18
1 21 | 30 19
0 22 | 25 31 20

Drawn By: Title: Version:

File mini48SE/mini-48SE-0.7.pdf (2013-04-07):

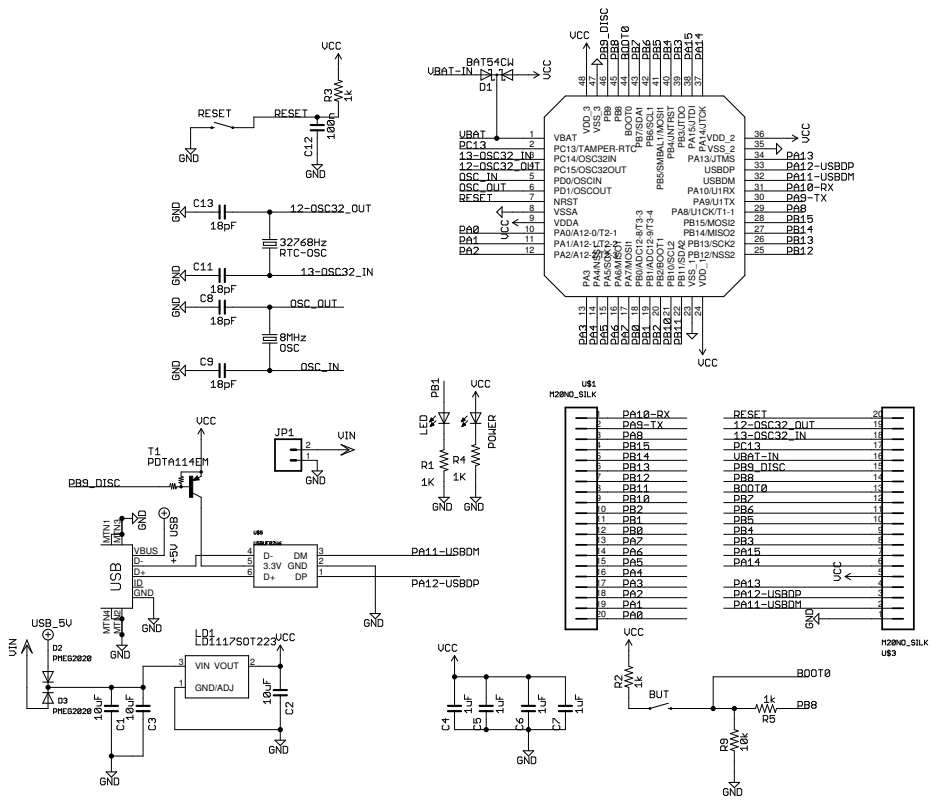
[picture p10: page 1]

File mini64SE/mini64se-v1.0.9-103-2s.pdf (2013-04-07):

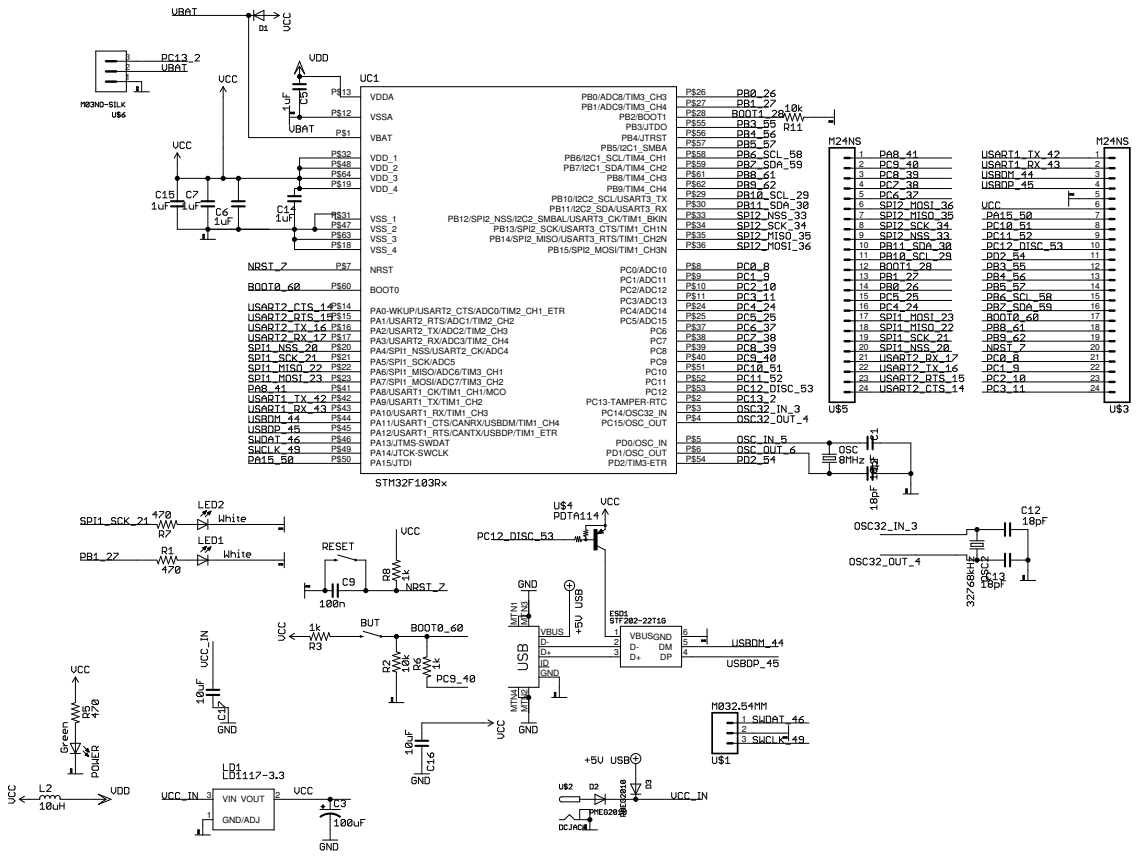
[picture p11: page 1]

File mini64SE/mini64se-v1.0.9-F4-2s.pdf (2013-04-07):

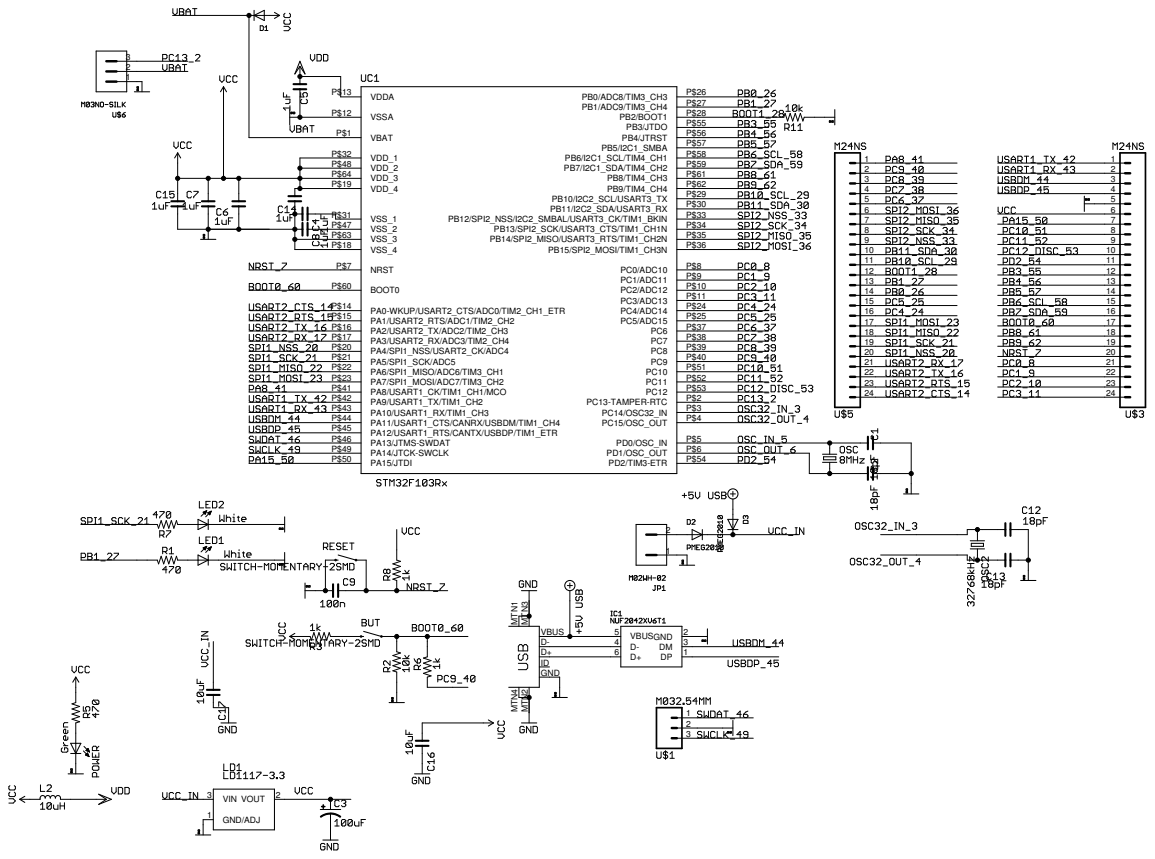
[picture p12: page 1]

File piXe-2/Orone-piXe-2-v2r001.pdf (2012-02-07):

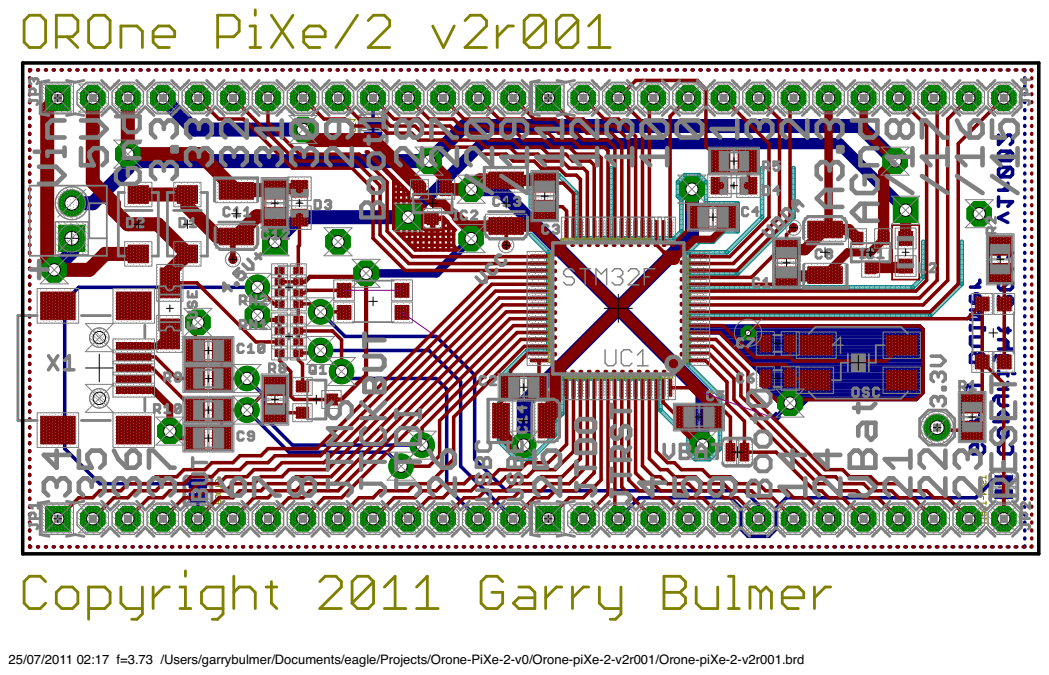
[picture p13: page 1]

25/07/2011 02:17 f=3.73 /Users/garrybulmer/Documents/eagle/Projects/Orone-PiXe-2-v0/Orone-piXe-2-v2r001/Orone-piXe-2-v2r001.brd

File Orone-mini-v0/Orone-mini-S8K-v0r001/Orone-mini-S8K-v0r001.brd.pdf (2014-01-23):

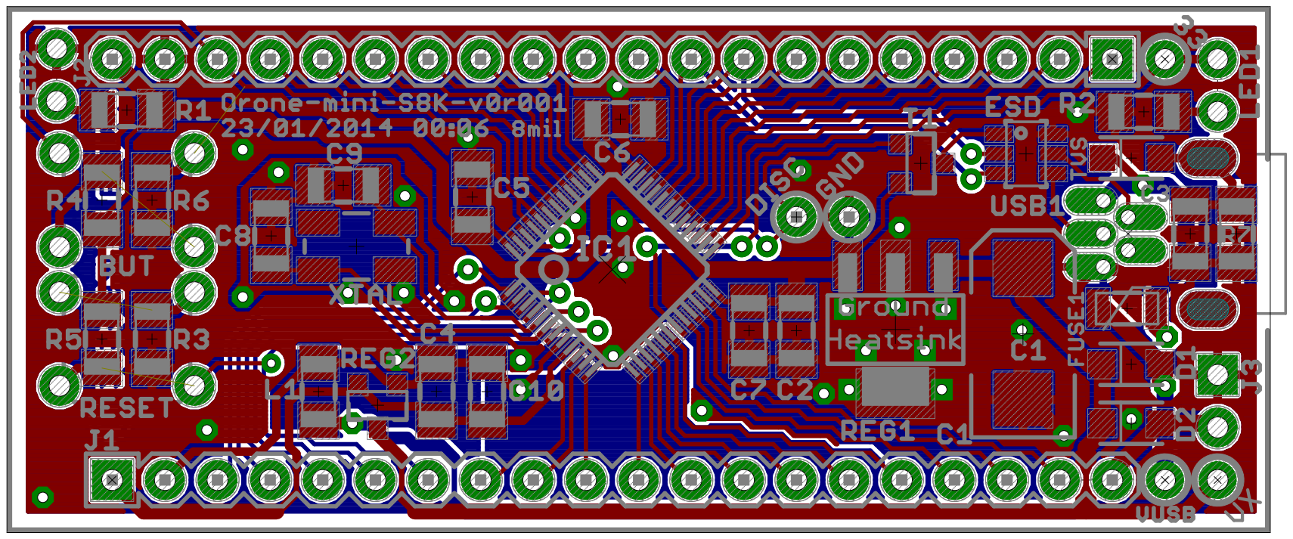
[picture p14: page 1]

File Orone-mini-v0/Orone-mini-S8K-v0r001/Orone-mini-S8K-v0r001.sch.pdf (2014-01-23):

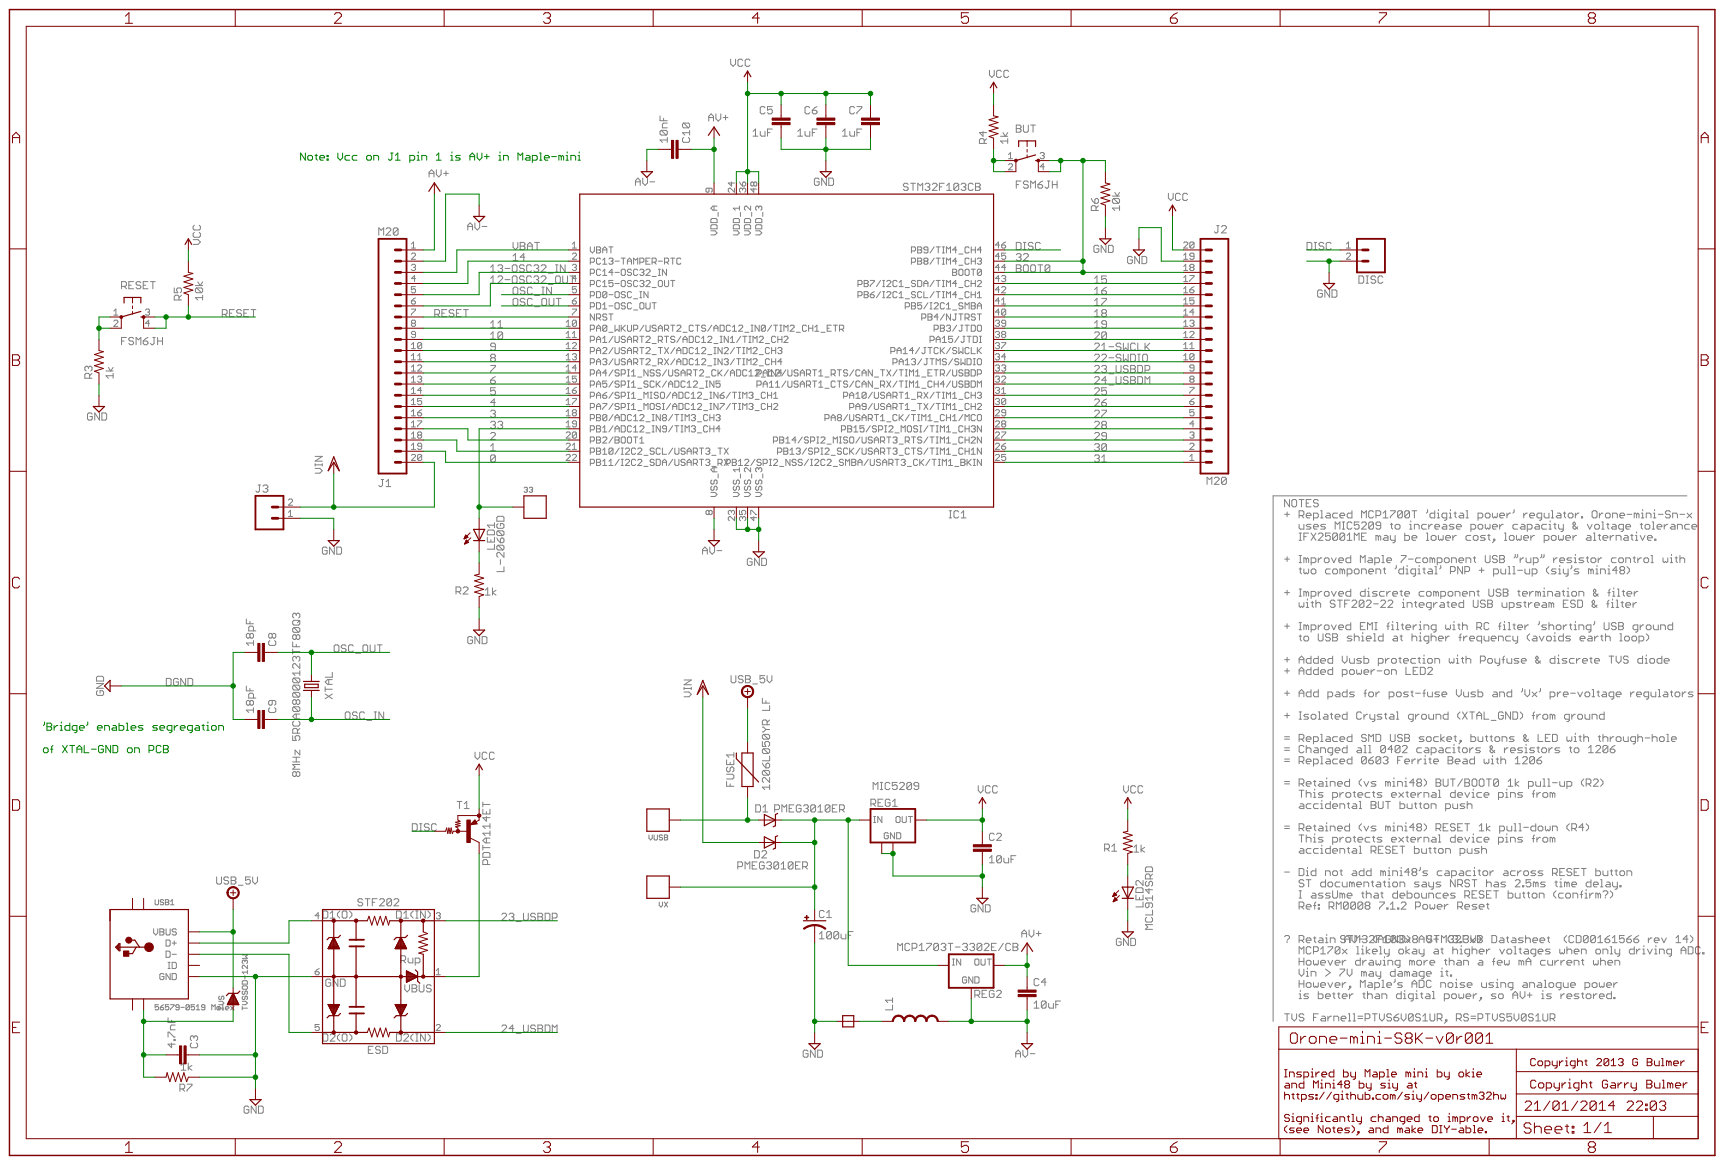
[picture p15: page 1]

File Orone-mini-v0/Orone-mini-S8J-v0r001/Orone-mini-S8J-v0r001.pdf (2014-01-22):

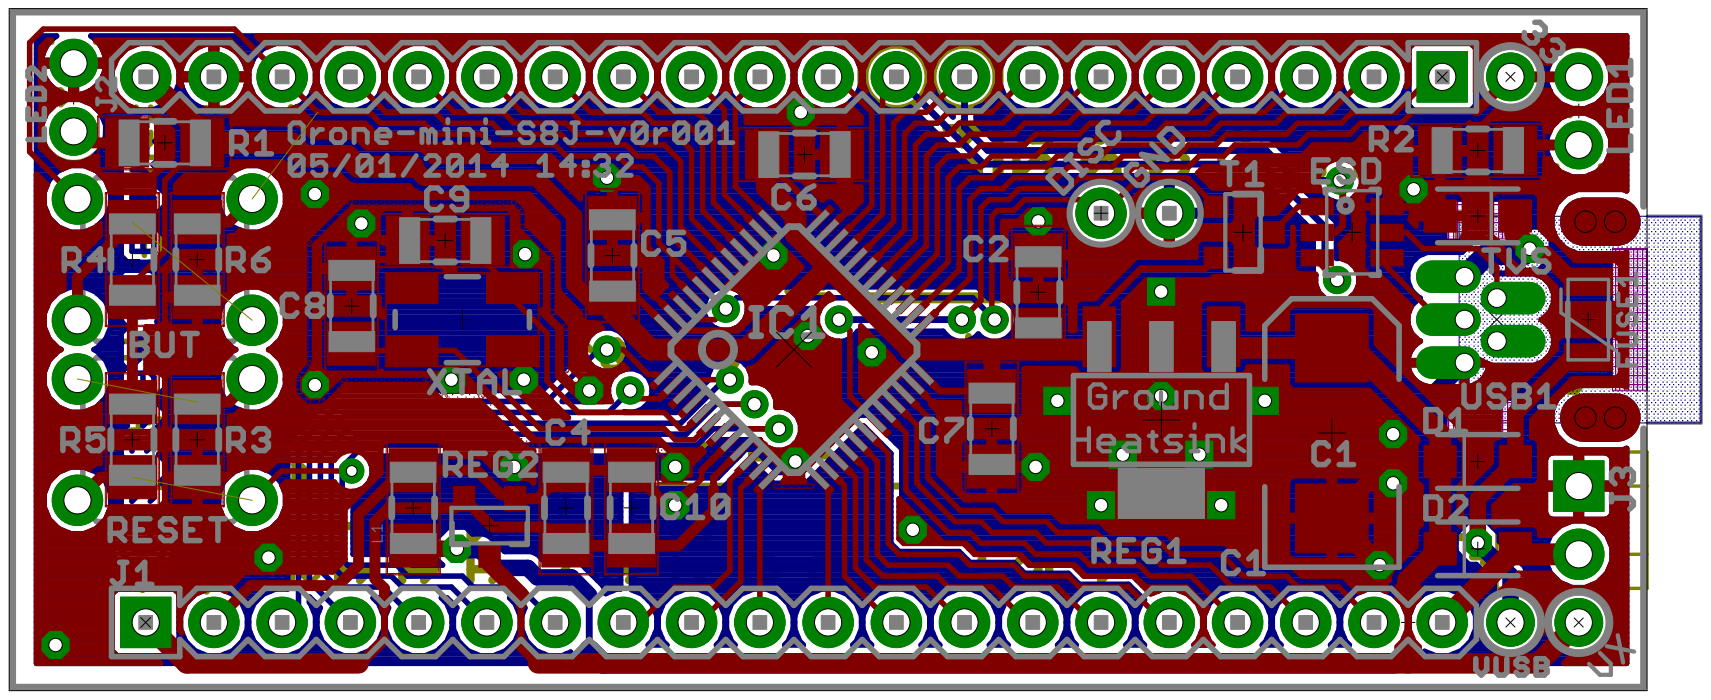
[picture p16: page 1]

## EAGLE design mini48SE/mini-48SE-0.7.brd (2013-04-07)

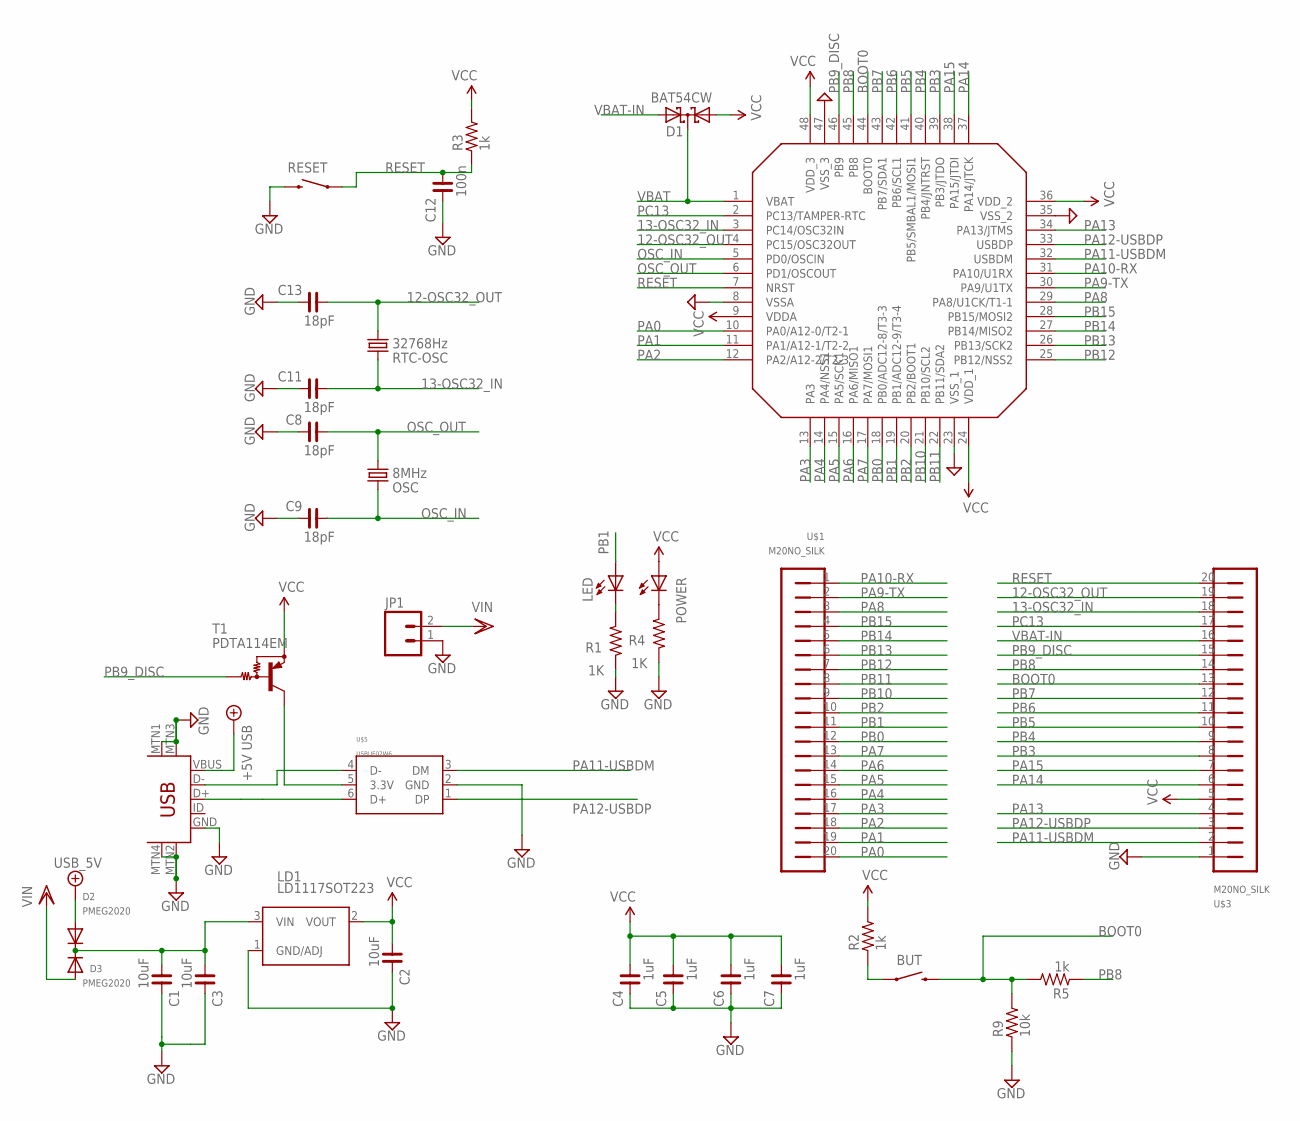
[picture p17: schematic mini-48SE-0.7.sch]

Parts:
BUT: SWITCH-MOMENTARY-2TS-1185; TS1185
C1, C3: 10uF; C0603
C2: 10uF; C0805
C4, C5, C6, C7: 1uF; C0603
C8, C9, C11, C13: 18pF; C0603
C12: 100n; C0603
D1: BAT54CW; SOT323R
D2, D3: PMEG2020; SOD-323
JP1: M02-JST-2MM-SMT; JST-2-SMD
LD1: LD1117SOT223; SOT223
LED: LED; CHIPLED_1206
OSC: 8MHz; TC26H-M
POWER: green; CHIP-LED0603
R1, R4: 1K; R0603
R2, R3, R5: 1k; R0603
R9: 10k; R0603
RESET: SWITCH-MOMENTARY-2TS-1185; TS1185
RTC-OSC: 32768Hz; TC26H-M
T1: PDTA114EM; SOT323R
U$1, U$3: M20NO_SILK; 1X20_NO_SILK
U$4: STM32F103_48; LQFP48-7X7
U$5: USBUF02W6; SC70-6
USB: USB-MINIB-5PIN; USB-MINIB

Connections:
12-OSC32_OUT: C13.1, RTC-OSC.1, U$3.19, U$4.4 (PC15/OSC32OUT)
13-OSC32_IN: C11.1, RTC-OSC.2, U$3.18, U$4.3 (PC14/OSC32IN)
+5V/2: D2.A, USB.VBUS
BOOT0: BUT.2, R5.2, R9.2, U$3.13, U$4.44 (BOOT0)
DGND: C1.2, C2.2, C3.2, C4.2, C5.2, C6.2, C7.2, C8.2, C9.2, C11.2, C12.2, C13.2, JP1.1, LD1.1 (GND/ADJ), R1.1, R4.1, R9.1, RESET.2, U$3.1, U$4.8 (VSSA), U$4.23 (VSS_1), U$4.35 (VSS_2), U$4.47 (VSS_3), U$5.2 (GND), USB.GND, USB.MTN1 (MTN2), USB.MTN2 (MTN3), USB.MTN3 (MTN1), USB.MTN4
unnamed: BUT.1, R2.1
unnamed: LED.C, R1.2
unnamed: POWER.C, R4.2
unnamed: C1.1, C3.1, D2.C, D3.C, LD1.3 (VIN)
unnamed: T1.3 (C), U$5.5 (3.3V)
unnamed: U$5.4 (D-), USB.D-
unnamed: U$5.6 (D+), USB.D+
OSC_IN: C9.1, OSC.2, U$4.5 (PD0/OSCIN)
OSC_OUT: C8.1, OSC.1, U$4.6 (PD1/OSCOUT)
PA0: U$1.20, U$4.10 (PA0/A12-0/T2-1)
PA1: U$1.19, U$4.11 (PA1/A12-1/T2-2)
PA2: U$1.18, U$4.12 (PA2/A12-2/T2-3)
PA3: U$1.17, U$4.13 (PA3)
PA4: U$1.16, U$4.14 (PA4/NSS1)
PA5: U$1.15, U$4.15 (PA5/SCK1)
PA6: U$1.14, U$4.16 (PA6/MISO1)
PA7: U$1.13, U$4.17 (PA7/MOSI1)
PA8: U$1.3, U$4.29 (PA8/U1CK/T1-1)
PA9-TX: U$1.2, U$4.30 (PA9/U1TX)
PA10-RX: U$1.1, U$4.31 (PA10/U1RX)
PA11-USBDM: U$3.2, U$4.32 (USBDM), U$5.3 (DM)
PA12-USBDP: U$3.3, U$4.33 (USBDP), U$5.1 (DP)
PA13: U$3.4, U$4.34 (PA13/JTMS)
PA14: U$3.6, U$4.37 (PA14/JTCK)
PA15: U$3.7, U$4.38 (PA15/JTDI)
PB0: U$1.12, U$4.18 (PB0/ADC12-8/T3-3)
PB1: LED.A, U$1.11, U$4.19 (PB1/ADC12-9/T3-4)
PB2: U$1.10, U$4.20 (PB2/BOOT1)
PB3: U$3.8, U$4.39 (PB3/JTDO)
PB4: U$3.9, U$4.40 (PB4/JNTRST)
PB5: U$3.10, U$4.41 (PB5/SMBAL1/MOSI1)
PB6: U$3.11, U$4.42 (PB6/SCL1)
PB7: U$3.12, U$4.43 (PB7/SDA1)
PB8: R5.1, U$3.14, U$4.45 (PB8)
PB9_DISC: T1.1 (B), U$3.15, U$4.46 (PB9)
PB10: U$1.9, U$4.21 (PB10/SCL2)
PB11: U$1.8, U$4.22 (PB11/SDA2)
PB12: U$1.7, U$4.25 (PB12/NSS2)
PB13: U$1.6, U$4.26 (PB13/SCK2)
PB14: U$1.5, U$4.27 (PB14/MISO2)
PB15: U$1.4, U$4.28 (PB15/MOSI2)
PC13: U$3.17, U$4.2 (PC13/TAMPER-RTC)
RESET: C12.1, R3.1, RESET.1, U$3.20, U$4.7 (NRST)
VBAT: D1.3 (CC), U$4.1 (VBAT)
VBAT-IN: D1.2 (A2), U$3.16
VCC: C2.1, C4.1, C5.1, C6.1, C7.1, D1.1 (A1), LD1.2 (VOUT), POWER.A, R2.2, R3.2, T1.2 (E), U$3.5, U$4.9 (VDDA), U$4.24 (VDD_1), U$4.36 (VDD_2), U$4.48 (VDD_3)
VIN: D3.A, JP1.2

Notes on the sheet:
BOOT0

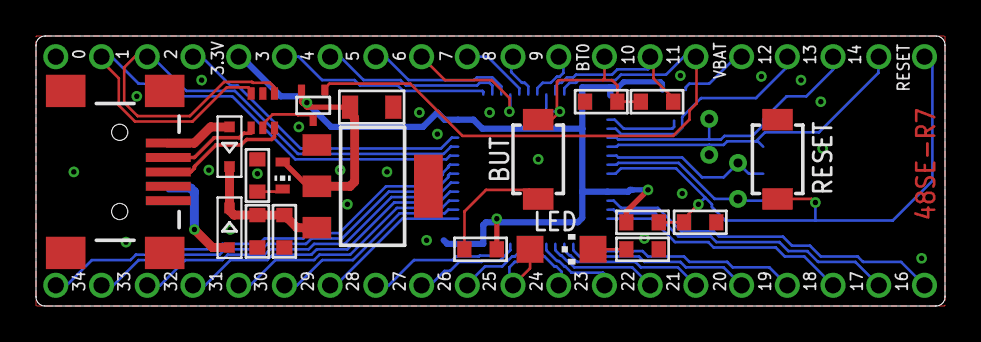
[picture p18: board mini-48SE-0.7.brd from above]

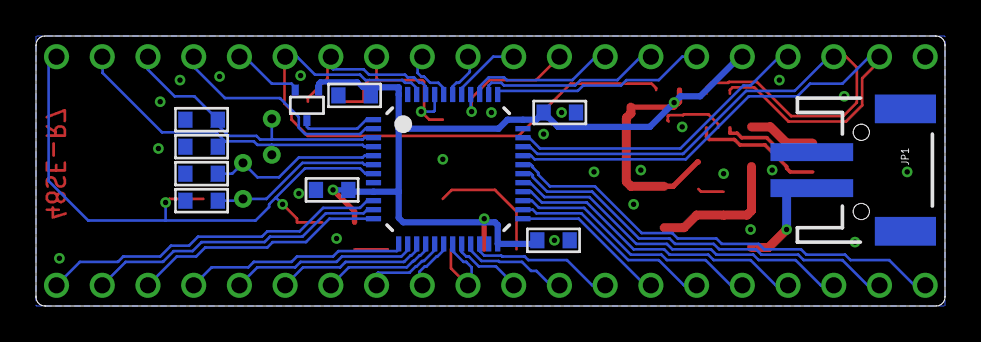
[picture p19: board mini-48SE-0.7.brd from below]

Board: 2 copper layers, 50.5 x 15.0 mm, 35 parts (13 on the bottom side), 52 nets.

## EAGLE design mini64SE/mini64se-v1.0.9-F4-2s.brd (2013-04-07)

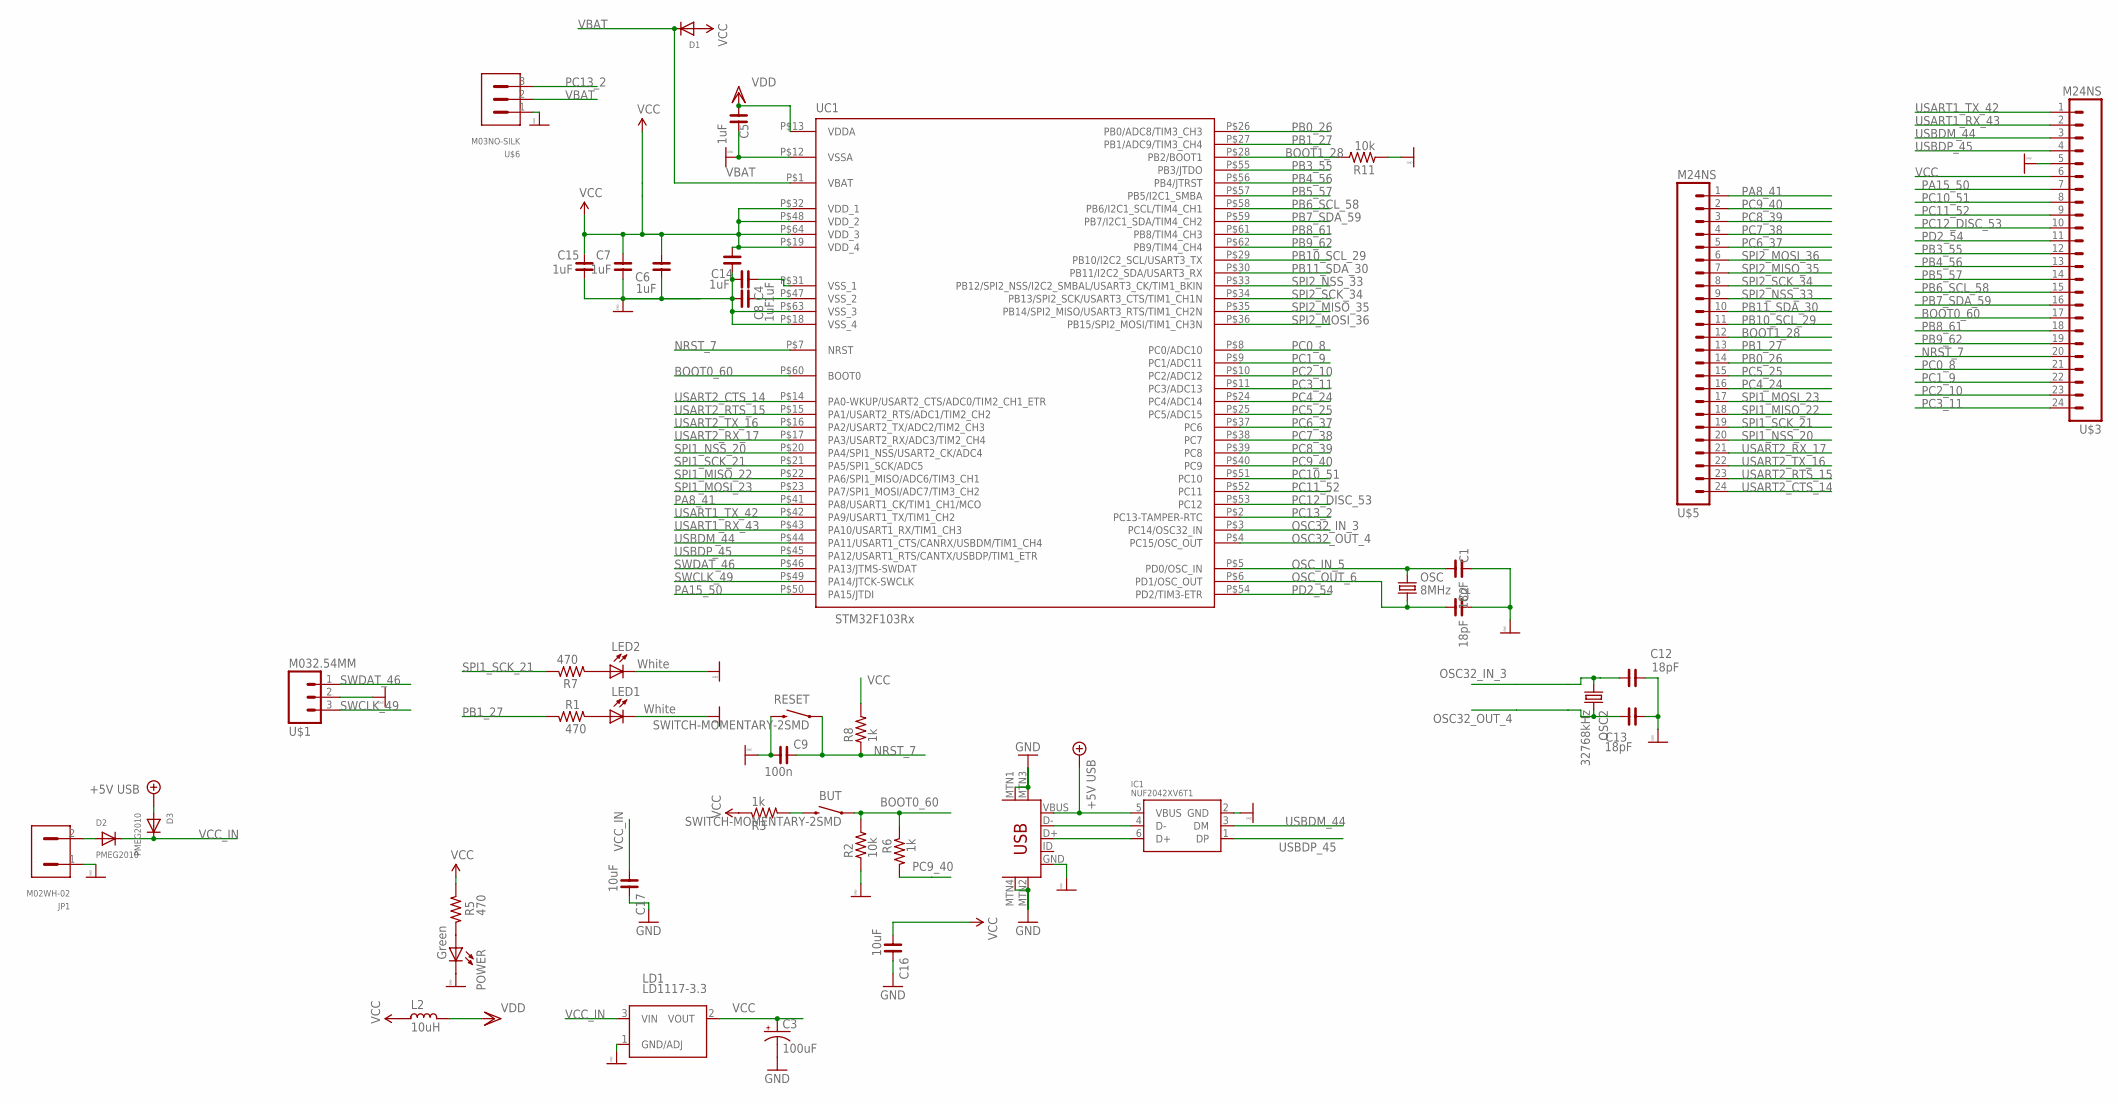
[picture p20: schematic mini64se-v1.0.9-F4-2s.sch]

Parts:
BUT: SWITCH-MOMENTARY-2SMD; TACTILE_SWITCH_SMD
C1, C2, C12, C13: 18pF; C0603
C3: 100uF; PANASONIC_C
C4, C5, C6, C7, C8, C14, C15: 1uF; C0603
C9: 100n; C0603
C16, C17: 10uF; C0805
D1: DIODESOD-123; SOD-123
D2, D3: PMEG2010; SOD-123
IC1: NUF2042XV6T1; SOT-563
JP1: M02WH-02; WH-02R
L2: 10uH; PM0603
LD1: LD1117-3.3; SOT223
LED1, LED2: White; CHIPLED_1206
OSC: 8MHz; HC49U-V
OSC2: 32768kHz; TC26H-M
POWER: Green; CHIP-LED0805
R1, R5, R7: 470; R0603
R2, R11: 10k; R0603
R3, R6, R8: 1k; R0603
RESET: SWITCH-MOMENTARY-2SMD; TACTILE_SWITCH_SMD
U$1: M032.54MM; 1X03_NO_SILK
U$3, U$5: M24NS; 1X24_NO_SILK
U$6: M03NO-SILK; 1X03_NO_SILK
UC1: STM32F103Rx; TQFP-10X10-64
USB: USB-MINIB-5PIN; USB-MINIB

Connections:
+5V: D3.A, IC1.5 (VBUS), USB.VBUS
BOOT0_60: BUT.1, R2.2, R6.1, U$3.17 (18), UC1.P$60 (BOOT0)
BOOT1_28: R11.2, U$5.12 (13), UC1.P$28 (PB2/BOOT1)
EXT_PWR: D2.A, JP1.2
GND: C1.1, C2.1, C3.-, C4.2, C5.1, C6.1, C7.1, C8.2, C9.1, C12.1, C13.1, C14.1, C15.1, C16.2, C17.2, IC1.2 (GND), JP1.1, LD1.1 (GND/ADJ), LED1.C, LED2.C, POWER.C, R2.1, R11.1, RESET.3 (2), U$1.2, U$3.5 (6), U$6.1, UC1.P$12 (VSSA), UC1.P$18 (VSS_4), UC1.P$63 (VSS_3), USB.GND, USB.MTN1 (MTN2), USB.MTN2 (MTN3), USB.MTN3 (MTN1), USB.MTN4
unnamed: POWER.A, R5.2
unnamed: BUT.3 (2), R3.2
unnamed: LED2.A, R7.2
unnamed: LED1.A, R1.1
unnamed: C4.1, UC1.P$31 (VSS_1)
unnamed: C8.1, UC1.P$47 (VSS_2)
unnamed: IC1.4 (D-), USB.D-
unnamed: IC1.6 (D+), USB.D+
NRST_7: C9.2, R8.1, RESET.1, U$3.20 (21), UC1.P$7 (NRST)
OSC32_IN_3: C12.2, OSC2.1, UC1.P$3 (PC14/OSC32_IN)
OSC32_OUT_4: C13.2, OSC2.2, UC1.P$4 (PC15/OSC_OUT)
OSC_IN_5: C1.2, OSC.2, UC1.P$5 (PD0/OSC_IN)
OSC_OUT_6: C2.2, OSC.1, UC1.P$6 (PD1/OSC_OUT)
PA8_41: U$5.1 (2), UC1.P$41 (PA8/USART1_CK/TIM1_CH1/MCO)
PA15_50: U$3.7 (8), UC1.P$50 (PA15/JTDI)
PB0_26: U$5.14 (15), UC1.P$26 (PB0/ADC8/TIM3_CH3)
PB1_27: R1.2, U$5.13 (14), UC1.P$27 (PB1/ADC9/TIM3_CH4)
PB3_55: U$3.12 (13), UC1.P$55 (PB3/JTDO)
PB4_56: U$3.13 (14), UC1.P$56 (PB4/JTRST)
PB5_57: U$3.14 (15), UC1.P$57 (PB5/I2C1_SMBA)
PB6_SCL_58: U$3.15 (16), UC1.P$58 (PB6/I2C1_SCL/TIM4_CH1)
PB7_SDA_59: U$3.16 (17), UC1.P$59 (PB7/I2C1_SDA/TIM4_CH2)
PB8_61: U$3.18 (19), UC1.P$61 (PB8/TIM4_CH3)
PB9_62: U$3.19 (20), UC1.P$62 (PB9/TIM4_CH4)
PB10_SCL_29: U$5.11 (12), UC1.P$29 (PB10/I2C2_SCL/USART3_TX)
PB11_SDA_30: U$5.10 (11), UC1.P$30 (PB11/I2C2_SDA/USART3_RX)
PC0_8: U$3.21 (22), UC1.P$8 (PC0/ADC10)
PC1_9: U$3.22 (23), UC1.P$9 (PC1/ADC11)
PC2_10: U$3.23 (24), UC1.P$10 (PC2/ADC12)
PC3_11: U$3.24 (25), UC1.P$11 (PC3/ADC13)
PC4_24: U$5.16 (17), UC1.P$24 (PC4/ADC14)
PC5_25: U$5.15 (16), UC1.P$25 (PC5/ADC15)
PC6_37: U$5.5 (6), UC1.P$37 (PC6)
PC7_38: U$5.4 (5), UC1.P$38 (PC7)
PC8_39: U$5.3 (4), UC1.P$39 (PC8)
PC9_40: R6.2, U$5.2 (3), UC1.P$40 (PC9)
PC10_51: U$3.8 (9), UC1.P$51 (PC10)
PC11_52: U$3.9 (10), UC1.P$52 (PC11)
PC12_DISC_53: U$3.10 (11), UC1.P$53 (PC12)
PC13_2: U$6.3, UC1.P$2 (PC13-TAMPER-RTC)
PD2_54: U$3.11 (12), UC1.P$54 (PD2/TIM3-ETR)
SPI1_MISO_22: U$5.18 (19), UC1.P$22 (PA6/SPI1_MISO/ADC6/TIM3_CH1)
SPI1_MOSI_23: U$5.17 (18), UC1.P$23 (PA7/SPI1_MOSI/ADC7/TIM3_CH2)
SPI1_NSS_20: U$5.20 (21), UC1.P$20 (PA4/SPI1_NSS/USART2_CK/ADC4)
SPI1_SCK_21: R7.1, U$5.19 (20), UC1.P$21 (PA5/SPI1_SCK/ADC5)
SPI2_MISO_35: U$5.7 (8), UC1.P$35 (PB14/SPI2_MISO/USART3_RTS/TIM1_CH2N)
SPI2_MOSI_36: U$5.6 (7), UC1.P$36 (PB15/SPI2_MOSI/TIM1_CH3N)
SPI2_NSS_33: U$5.9 (10), UC1.P$33 (PB12/SPI2_NSS/I2C2_SMBAL/USART3_CK/TIM1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)
SPI2_SCK_34: U$5.8 (9), UC1.P$34 (PB13/SPI2_SCK/USART3_CTS/TIM1_CH1N)
SWCLK_49: U$1.3, UC1.P$49 (PA14/JTCK-SWCLK)
SWDAT_46: U$1.1, UC1.P$46 (PA13/JTMS-SWDAT)
USART1_RX_43: U$3.2 (3), UC1.P$43 (PA10/USART1_RX/TIM1_CH3)
USART1_TX_42: U$3.1 (2), UC1.P$42 (PA9/USART1_TX/TIM1_CH2)
USART2_CTS_14: U$5.24 (25), UC1.P$14 (PA0-WKUP/USART2_CTS/ADC0/TIM2_CH1_ETR)
USART2_RTS_15: U$5.23 (24), UC1.P$15 (PA1/USART2_RTS/ADC1/TIM2_CH2)
USART2_RX_17: U$5.21 (22), UC1.P$17 (PA3/USART2_RX/ADC3/TIM2_CH4)
USART2_TX_16: U$5.22 (23), UC1.P$16 (PA2/USART2_TX/ADC2/TIM2_CH3)
USBDM_44: IC1.3 (DM), U$3.3 (4), UC1.P$44 (PA11/USART1_CTS/CANRX/USBDM/TIM1_CH4)
USBDP_45: IC1.1 (DP), U$3.4 (5), UC1.P$45 (PA12/USART1_RTS/CANTX/USBDP/TIM1_ETR)
VBAT: D1.C, U$6.2, UC1.P$1 (VBAT)
VCC: C3.+, C6.2, C7.2, C14.2, C15.2, C16.1, D1.A, L2.2, LD1.2 (VOUT), R3.1, R5.1, R8.2, U$3.6 (7), UC1.P$19 (VDD_4), UC1.P$32 (VDD_1), UC1.P$48 (VDD_2), UC1.P$64 (VDD_3)
VCC_IN: C17.1, D2.C, D3.C, LD1.3 (VIN)
VDD: C5.2, L2.1, UC1.P$13 (VDDA)

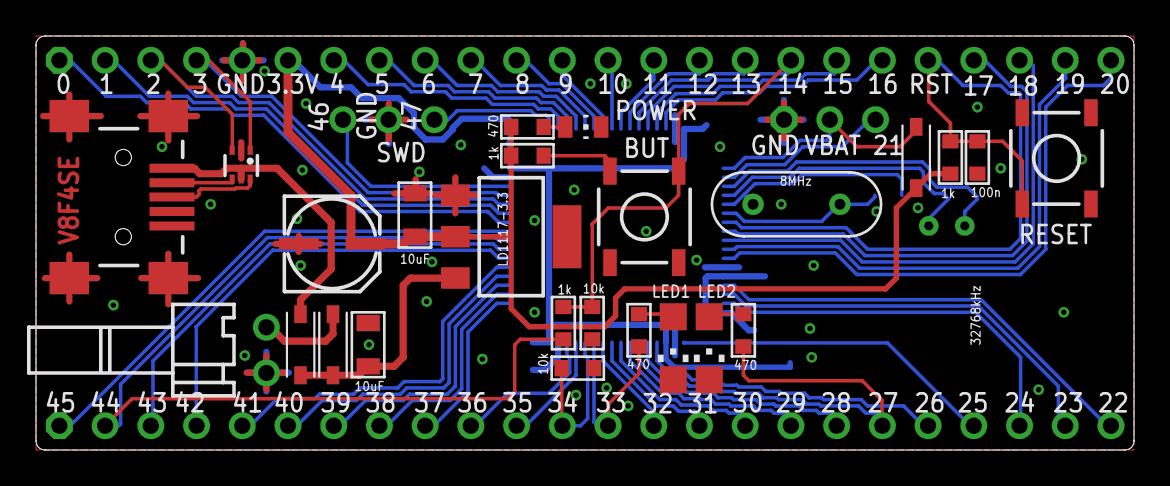
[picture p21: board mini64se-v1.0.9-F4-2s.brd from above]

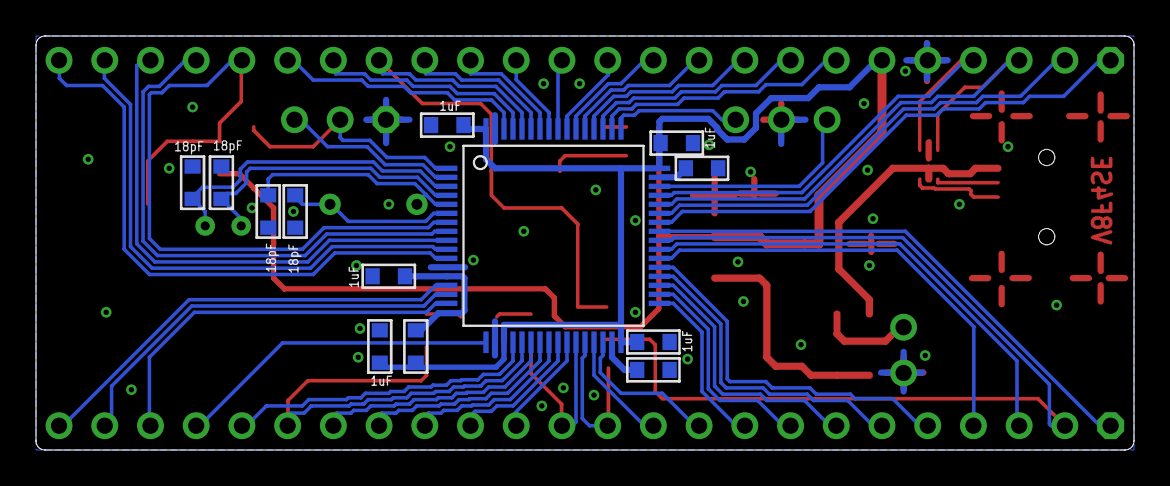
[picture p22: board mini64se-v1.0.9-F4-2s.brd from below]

Board: 4 copper layers, 61.0 x 23.0 mm, 43 parts (14 on the bottom side), 68 nets.

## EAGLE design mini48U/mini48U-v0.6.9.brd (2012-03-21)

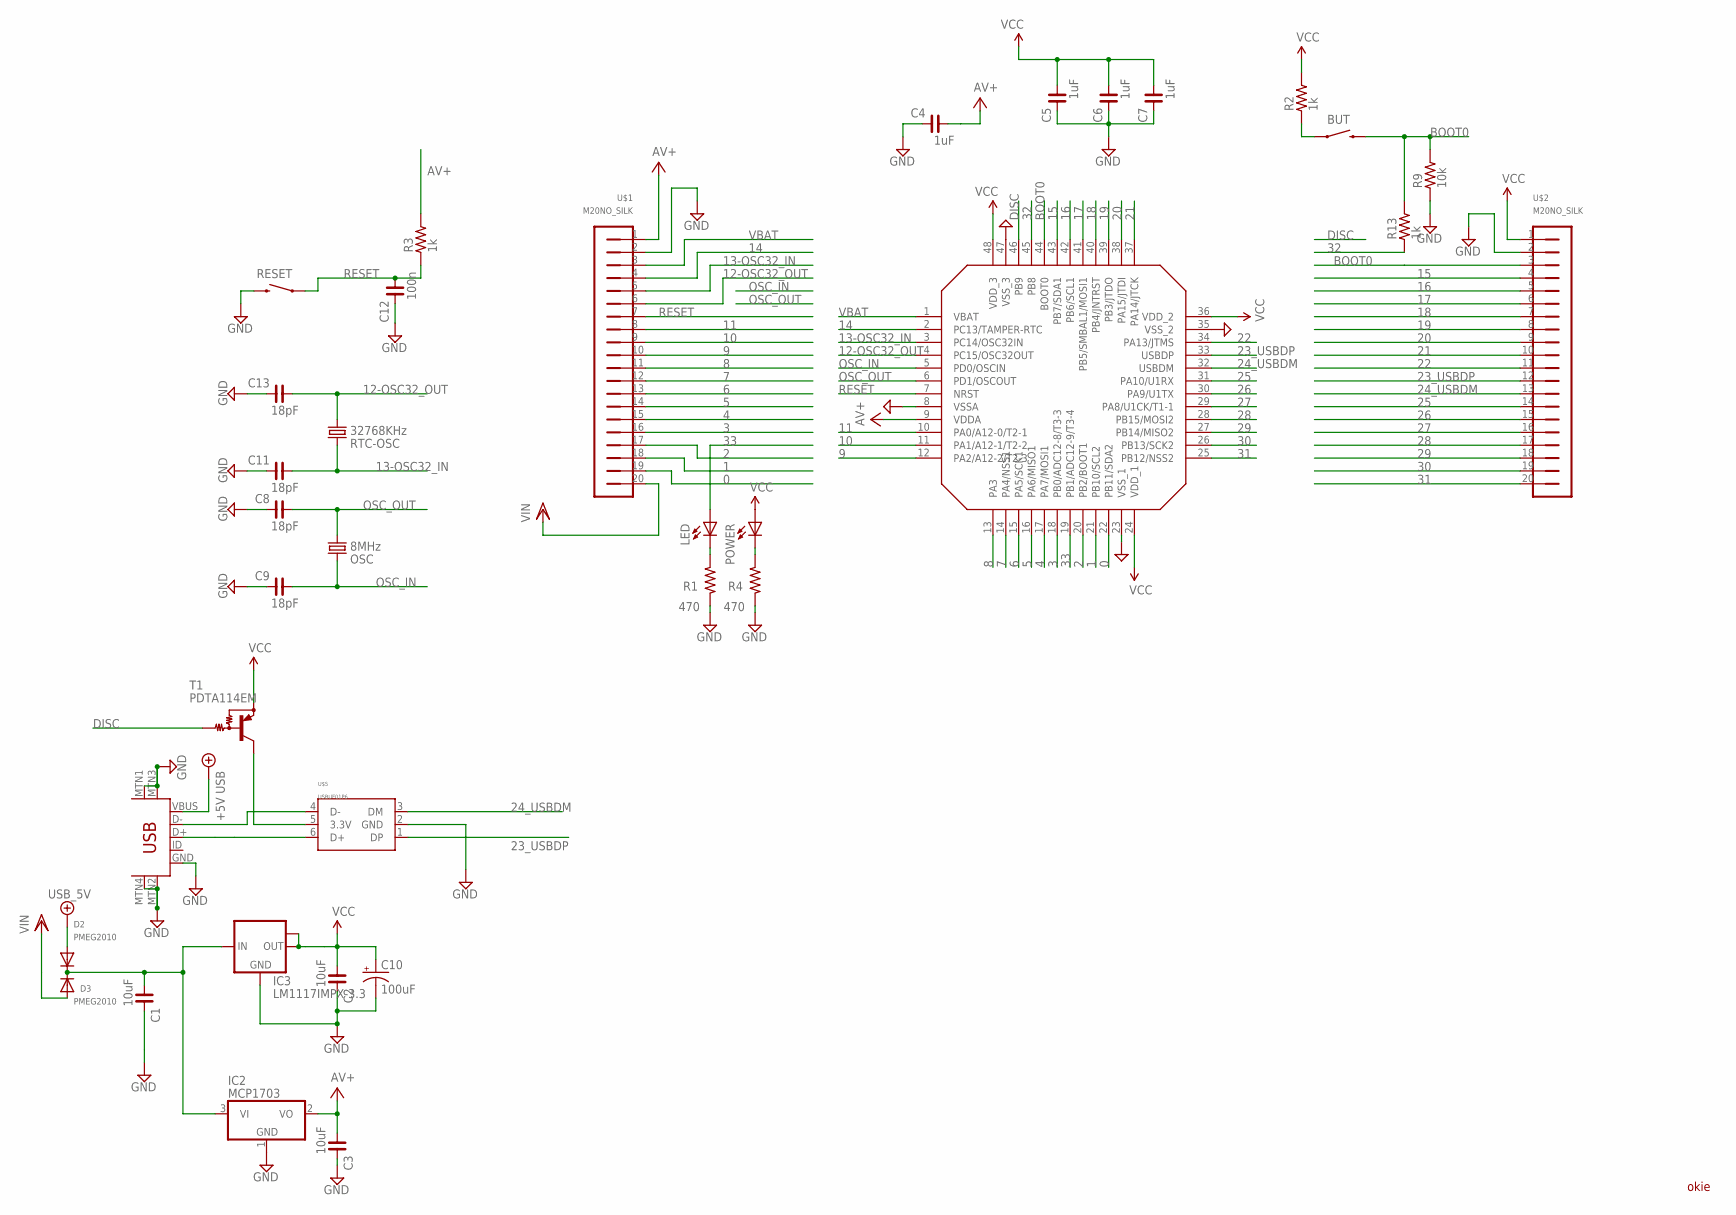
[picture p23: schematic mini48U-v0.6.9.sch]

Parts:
BUT: SWITCH-MOMENTARY-2KMR211_NO_GND; KMR211NG
C1, C2, C3: 10uF; C0805
C4, C5, C6, C7: 1uF; C0402
C8, C9, C11, C13: 18pF; C0402
C10: 100uF; EIA3528
C12: 100n; C0402
D2, D3: PMEG2010; SOD-323
IC2: MCP1703; SOT23-3
IC3: LM1117IMPX-3.3; SOT223
LED: LED; KA-3528ASYC
OSC: 8MHz; TC38H
POWER: green; CHIP-LED0603
R1, R4: 470; R0402
R2, R3, R13: 1k; R0402
R9: 10k; R0402
RESET: SWITCH-MOMENTARY-2KMR211_NO_GND; KMR211NG
RTC-OSC: 32768KHz; TC26H
T1: PDTA114EM; SOT-723
U$1, U$2: M20NO_SILK; 1X20_NO_SILK
U$4: STM32F103_48; LQFP48-7X7
U$5: USBUF01P6; SOT-666
USB: USB-MINIB-5PIN; USB-MINIB

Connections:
0: U$1.19, U$4.22 (PB11/SDA2)
1: U$1.18, U$4.21 (PB10/SCL2)
2: U$1.17, U$4.20 (PB2/BOOT1)
3: U$1.16, U$4.18 (PB0/ADC12-8/T3-3)
4: U$1.15, U$4.17 (PA7/MOSI1)
5: U$1.14, U$4.16 (PA6/MISO1)
6: U$1.13, U$4.15 (PA5/SCK1)
7: U$1.12, U$4.14 (PA4/NSS1)
8: U$1.11, U$4.13 (PA3)
9: U$1.10, U$4.12 (PA2/A12-2/T2-3)
10: U$1.9, U$4.11 (PA1/A12-1/T2-2)
11: U$1.8, U$4.10 (PA0/A12-0/T2-1)
12-OSC32_OUT: C13.1, RTC-OSC.1, U$1.6, U$4.4 (PC15/OSC32OUT)
13-OSC32_IN: C11.1, RTC-OSC.2, U$1.5, U$4.3 (PC14/OSC32IN)
14: U$1.4, U$4.2 (PC13/TAMPER-RTC)
15: U$2.4, U$4.43 (PB7/SDA1)
16: U$2.5, U$4.42 (PB6/SCL1)
17: U$2.6, U$4.41 (PB5/SMBAL1/MOSI1)
18: U$2.7, U$4.40 (PB4/JNTRST)
19: U$2.8, U$4.39 (PB3/JTDO)
20: U$2.9, U$4.38 (PA15/JTDI)
21: U$2.10, U$4.37 (PA14/JTCK)
22: U$2.11, U$4.34 (PA13/JTMS)
23_USBDP: U$2.12, U$4.33 (USBDP), U$5.1 (DP)
24_USBDM: U$2.13, U$4.32 (USBDM), U$5.3 (DM)
25: U$2.14, U$4.31 (PA10/U1RX)
26: U$2.15, U$4.30 (PA9/U1TX)
27: U$2.16, U$4.29 (PA8/U1CK/T1-1)
28: U$2.17, U$4.28 (PB15/MOSI2)
29: U$2.18, U$4.27 (PB14/MISO2)
30: U$2.19, U$4.26 (PB13/SCK2)
31: U$2.20, U$4.25 (PB12/NSS2)
32: R13.1, U$4.45 (PB8)
33: LED.A, U$4.19 (PB1/ADC12-9/T3-4)
+5V/2: D2.A, USB.VBUS
AV+: C3.1, C4.1, IC2.2 (VO), R3.2, U$1.1, U$4.9 (VDDA)
BOOT0: BUT.2, R9.2, R13.2, U$2.3, U$4.44 (BOOT0)
DGND: C1.2, C2.2, C3.2, C4.2, C5.2, C6.2, C7.2, C8.2, C9.2, C10.C (-), C11.2, C12.2, C13.2, IC2.1 (GND), IC3.1 (GND), R1.1, R4.1, R9.1, RESET.2, U$1.2, U$2.2, U$4.8 (VSSA), U$4.23 (VSS_1), U$4.35 (VSS_2), U$4.47 (VSS_3), U$5.2 (GND), USB.GND, USB.MTN1 (MTN2), USB.MTN2 (MTN3), USB.MTN3 (MTN1), USB.MTN4
DISC: T1.1 (B), U$4.46 (PB9)
unnamed: BUT.1, R2.1
unnamed: LED.C, R1.2
unnamed: POWER.C, R4.2
unnamed: C1.1, D2.C, D3.C, IC2.3 (VI), IC3.3 (IN)
unnamed: T1.3 (C), U$5.5 (3.3V)
unnamed: U$5.4 (D-), USB.D-
unnamed: U$5.6 (D+), USB.D+
OSC_IN: C9.1, OSC.2, U$4.5 (PD0/OSCIN)
OSC_OUT: C8.1, OSC.1, U$4.6 (PD1/OSCOUT)
RESET: C12.1, R3.1, RESET.1, U$1.7, U$4.7 (NRST)
VBAT: U$1.3, U$4.1 (VBAT)
VCC: C2.1, C5.1, C6.1, C7.1, C10.A (+), IC3.2 (OUT), IC3.TAB (OUT1), POWER.A, R2.2, T1.2 (E), U$2.1, U$4.24 (VDD_1), U$4.36 (VDD_2), U$4.48 (VDD_3)
VIN: D3.A, U$1.20

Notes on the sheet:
okie
BOOT0

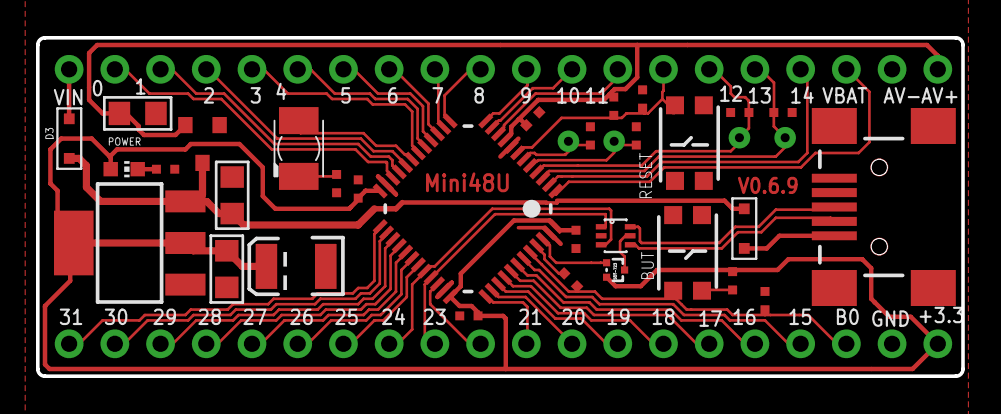
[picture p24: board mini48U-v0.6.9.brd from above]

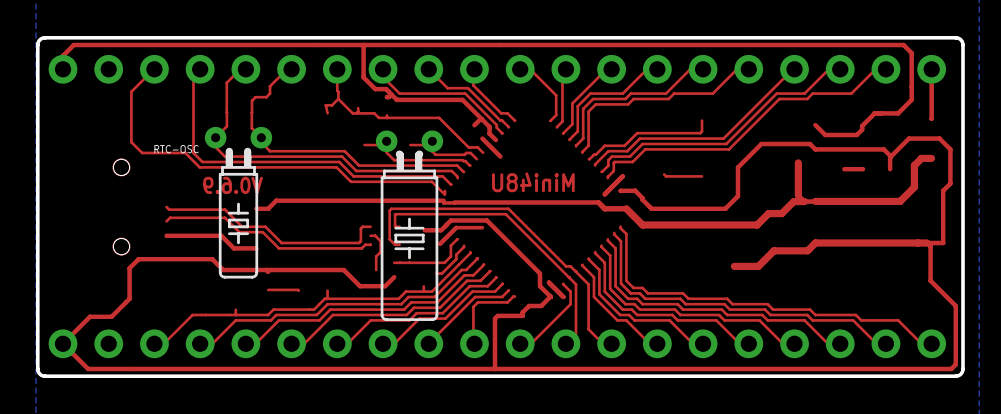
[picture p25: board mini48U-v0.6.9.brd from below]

Board: 2 copper layers, 51.4 x 18.8 mm, 35 parts (2 on the bottom side), 52 nets.

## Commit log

2012-01-29 added Mini64 board
    [mini64-v0.9.8.brd, mini64-v0.9.8.sch]
2012-01-30 Original r0 variant of MM4 board added
    [MM4_r0.brd, MM4_r0.sch]
2012-01-31 Updated to give brief summary of the two STM32 boards, thanks to siy for Mini64 and rod for MM4
2012-02-05 Added Mini48 design.
    [mini48-v0.3.brd, mini48-v0.3.sch]
2012-02-07 Added piXe-2 - Work-In-Progress - 'Stamp' format, DIL board for 64pin STM32F103
2012-02-16 Added Mini48, minor cleanups
    [mini48U-v0.6.1.brd, mini48U-v0.6.1.sch]
2012-03-18 Added new version of Mini48U
    [mini48U-v0.6.9.brd, mini48U-v0.6.9.sch]
2013-04-04 Added three new designs.
    [mini-48SE-0.7.brd, mini-48SE-0.7.sch, mini64se-v1.0.9-103-2s.brd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]
2013-04-11 Added First version of Orone-mini-S8A, DIY-able Maple-mini-like board.
    First Commit of Orone-mini and Orone-mini-S8A-v0r001, Maple-mini-like STM32F board.
    [Orone-mini-S8A-v0r001.brd, Orone-mini-S8A-v0r001.sch]
2013-04-12 Added USB-Mini-Molex.lbr which contains three different footprints for the Molex socket. Updated README files to reflect untested status.
2013-04-12 Segregated ground plane under ADC signals re-connected to av-. Intent is to provide a less noisy ground plane under ADC input signals.
    [Orone-mini-S8A-v0r001.brd]
2013-04-14 Created initial Bill of Materials (BoM) using RS, Farnell & Future (for ESD only). TBD: 100uF capacitor. Modified CAD to hide redundant airwires.
    [Orone-mini-S8A-v0r001.bom.csv, Orone-mini-S8A-v0r001.brd, Orone-mini-S8A-v0r001.sch]
2013-04-15 Added Orone-mini-S8C, modified BoMs for S8A and S8C variants, added markdown to README
    [Orone-mini-S8C-v0r001.bom.csv, Orone-mini-S8C-v0r001.brd, Orone-mini-S8C-v0r001.sch]
2013-04-15 Tweaked position of User LED (pin 33) and added thru-hole pad for DISC (PB9) putting holes onto 0.1" grid. These give access to the two signals not on pin-headers, though the User LED must not be fit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
    [Orone-mini-S8C-v0r001.brd, Orone-mini-S8C-v0r001.sch]
2013-04-16 Updated README's describing 'Tweaked' position of User LED pads and DISC 'via' to give access to signals.
2013-04-16 First checkin of Orone-mini-S8D, puts User LED (33) next to pin header, and DISC signal onto a pad. Also changed position of Power-on and User LED.
    [Orone-mini-S8D-v0r001.brd, Orone-mini-S8D-v0r001.sch]
2013-04-18 Moved BoM files into their own directory, and added costs from RS and Future.
    [Orone-mini-S8-v0r001.bom.csv, Orone-mini-S8A-v0r001.bom.csv, Orone-mini-S8C-v0r001.bom.csv]
2013-04-23 Small adjustments to PCB.
    [Orone-mini-S8D-v0r001.brd, Orone-mini-S8D-v0r001.sch]
2013-04-29 Added 8mil/8mil S8H design.
    [Orone-mini-S8H-v0r001.brd, Orone-mini-S8H-v0r001.sch]
2013-04-29 Added Digikey bom, created by ventosus.
    [Orone-mini-S8-v0r001.Digikey.bom.csv]
2013-05-05 Added English Headings and deleted lines containing dates from ventosus Digi-Key BoM. Slightly improved wording on original BoM.
    [Orone-mini-S8-v0r001.Digikey.bom.csv, Orone-mini-S8-v0r001.bom.csv]
2013-05-05 Added Vusb & Vx (regulator) pads. Rerouted ground, analogue ground, MCU top-side copper pour, and USB D+ to reduce noise.
    [Orone-mini-S8D-v0r001.brd, Orone-mini-S8D-v0r001.sch]
2013-05-05 Updated comments on Schematic to reflect added voltage pads.
    [Orone-mini-S8D-v0r001.sch]
2013-05-06 Changed voltage pads (Vusb & Vx) to match other (e.g. S8D) boards. Adjusted ground for better return path. Reduced USB R-pull-up 'stub track' for less signal reflection. Moved LED1 so 3mm LED could b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
    [Orone-mini-S8H-v0r001.brd, Orone-mini-S8H-v0r001.sch]
2013-05-20 Adjusted USB 'DISC' pad to support 2 x 0.1" header, intended to help STM32F303 boot from USB using built-in bootloader. Increased clearance between STM32F and capacitors, intended to help assembly an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
    [Orone-mini-S8E-v0r001.brd, Orone-mini-S8E-v0r001.sch]
2013-05-22 Initial release of OSH Park compatible CAM file. Changed from OSHPark's normal CAM file to support User 'top' (Eagle bottom) silk screen Updated Orone-mini-S8H to match Orone-mini-S8E: Adjusted USB '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
    [Orone-mini-S8E-v0r001.brd, Orone-mini-S8H-v0r001.brd, Orone-mini-S8H-v0r001.sch]
2013-05-23 Updated README to indicate that 'succeeded' boards are not likely to be tested.
2013-05-23 Modified silk screen 'USB only' to avoid problems generating reversed text. Changed all _bsilk layer text and lines to bPlace layer; Eagle does better error checks for silk screen overalpping with co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
    [Orone-mini-S8E-v0r001.brd, Orone-mini-S8H-v0r001.brd]
2014-01-05 Added Orone-mini-S8J-v0r001. USB EMI/ESDi replaced, analogue supply and ground plane reworked.
    [Orone-mini-S8J-v0r001.brd, Orone-mini-S8J-v0r001.sch]
2014-01-22 fixed two airwires, updated README files
    [Orone-mini-S8J-v0r001.brd]
2014-01-23 New S8K: DISC+Ground header moved, and connected USB shield to USB ground
    [Orone-mini-S8K-v0r001.brd, Orone-mini-S8K-v0r001.sch]
